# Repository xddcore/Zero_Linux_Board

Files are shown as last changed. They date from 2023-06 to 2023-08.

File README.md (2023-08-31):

<!--
 * @Author: Chengsen Dong 1034029664@qq.com
 * @Date: 2023-06-09 21:19:34
 * @LastEditors: Chengsen Dong 1034029664@qq.com
 * @LastEditTime: 2023-08-31 16:49:50
 * @FilePath: /Zero_Linux_Board/README.md
 * @Description: 这是默认设置,请设置`customMade`, 打开koroFileHeader查看配置 进行设置: https://github.com/OBKoro1/koro1FileHeader/wiki/%E9%85%8D%E7%BD%AE
-->
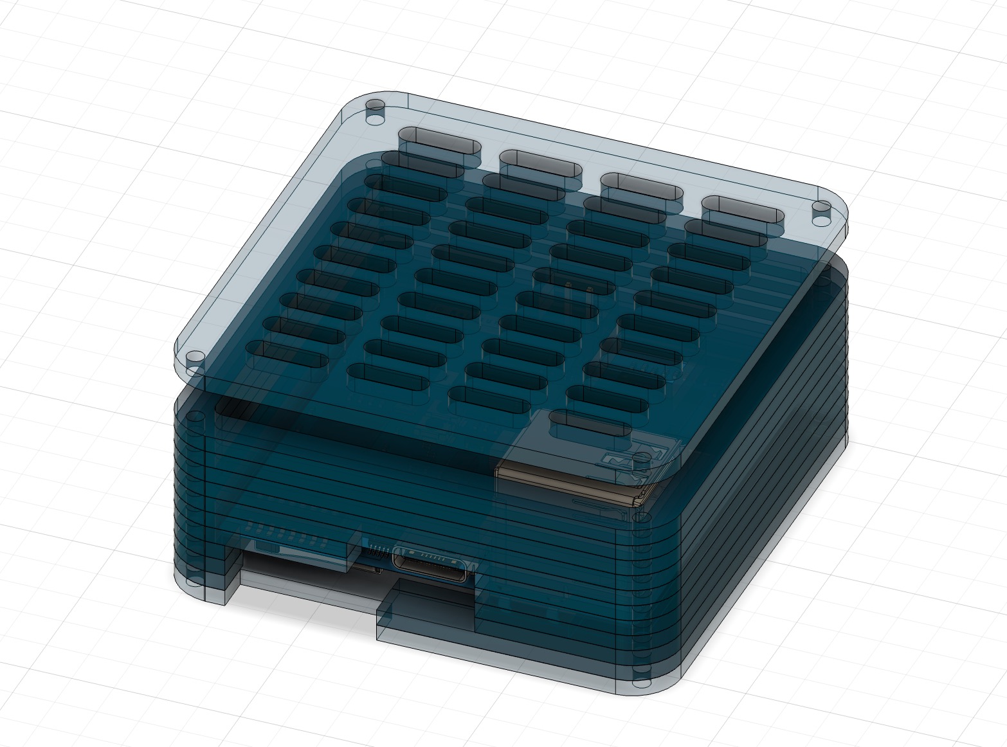
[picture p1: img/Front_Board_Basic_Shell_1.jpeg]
基础版正面1

# Zero Linux Board - 一个Linux小电脑。

>如果你喜欢此项目，欢迎为本项目点一个Star🌟

**核心板视频介绍**：[【自制】圆梦Linux小电脑](https://www.bilibili.com/video/BV1nN411S7BC)

**开源仓库介绍**：[【自制|开源】小白也可以轻松复现的Linux小电脑](https://www.bilibili.com/video/BV17u411V7ws/)

**透明探索版便携式小电脑**:[【自制】技术宅up耗时两个月，自制掌上触屏小电脑【硬核】【透明探索版】](https://www.bilibili.com/video/BV16h4y1Q7jv/)

## 介绍
本项目是xddcore同学在2023年6月2日启动的一个Linux开发板项目。本项目旨在纪念学生时代的结束(从初二至今9年的电子编程折腾生涯)。同时，设计一块板子来满足一些需要Linux生态但是又不需要很强性能的场景。

## 特性
1. **紧凑的设计**。PCB尺寸`49mm*49mm*1.6mm`，带壳尺寸`59mm*59mm*27mm`。
2. **差不多性能**。内置全志F1C200S(`ARM9@400Mhz+`)和RP2040(`双Cortex M0+处理器核心，最高133MHz`)。
3. **方便的开发方式**。仅一个Type-C接口可完成对F1C200S和RP2040的开发。另外还可通过F1C200S直接对RP2040进行编程。
4. **充分的外设**。`USB Hub(USB2.0*2)`，`2.4 GHz WIFI`，`3W扬声器`，`锂电池充放电管理`，`MPU6050`等。
5. **扩展板支持**。RP2040GPIO全引出(除2个ADC引脚外)，F1C200S部分核心外设引出。在后期将支持`ISP屏幕/墨水屏➕摄像头➕麦克风一体化扩展板`。
6. **透明探索版**。外壳主体采用12块2mm透明亚克力拼装而成。

- [Zero Linux Board - 一个Linux小电脑。](#)
  * [介绍](#介绍)
  * [特性](#特性)
  * [关于量产拼单活动](#关于量产拼单活动)
  * [目录结构](#0-目录结构)
  * [复现指南](#1-复现指南)
    + [1.1 硬件](#11-硬件)
      - [1.1.1 核心板PCB](#111-核心板pcb)
      - [1.1.2 扩展板PCB](#112-扩展板pcb)
      - [1.1.3 外壳](#113-外壳)
      - [1.1.4 其他硬件](#114-其他硬件)
      - [1.1.5 Type-C连接方式](#115-type-c连接方式)
      - [1.1.6 Type-C拨码开关配置](#116-type-c拨码开关配置)
    + [1.2 软件](#12-软件)
      - [1.2.1 驱动支持情况:](#121-驱动支持情况)
      - [1.2.2 快速验证](#122-快速验证)
      - [1.2.3 U-Boot](#123-u-boot)
      - [1.2.4 Linux主线(5.10.186)](#124-linux主线510186)
      - [1.2.5 使用Buildroot创建一个简易的rootfs来调试内核](#125-使用buildroot创建一个简易的rootfs来调试内核)
      - [1.2.6 使用debian来作为rootfs(apt install很舒服)](#126-使用debian来作为rootfsapt-install很舒服)
      - [1.2.7 debian-番外篇](#127-debian-番外篇)
    + [1.3 驱动开发](#13-驱动开发)
      - [1.3.1 Linux音频](#131-linux音频)
      - [1.3.2 ESP8266EX WIFI驱动](#132-esp8266ex-wifi驱动)
      - [1.3.3 MPU6050驱动](#133-mpu6050驱动)
      - [1.3.4 2.8寸ISP电容触摸屏驱动➕LVGL](#134-28寸isp电容触摸屏驱动lvgl)
      - [1.3.5 树莓派RP2040 USB驱动](#135-树莓派rp2040-usb驱动)
      - [1.3.6 语音识别与交互驱动](#136-语音识别与交互驱动)
    + [1.4 玩法推荐](#14-玩法)
      - [1.4.1 显示系统信息](#141-在isp屏幕上显示系统信息)
      - [1.4.2 显示图片](#142-在isp屏幕上显示图片)
      - [1.4.3 视频播放](#143-在isp屏幕上视频播放)
      - [1.4.4 usb摄像头](#144-usb摄像头)
      - [1.4.5 本地音乐播放](#145-本地音乐播放)
      - [1.4.6 网易云音乐播放音乐播放](#146-网易云音乐播放音乐播放)
      - [1.4.7 6轴陀螺仪](#147-6轴陀螺仪)
      - [1.4.8 lvgl](#148-lvgl)
      - [1.4.9 rp2040编程](#149-rp2040编程)
      - [1.4.10 智能助手chatgpt-35](#1410-智能助手chatgpt-35)
      - [1.4.11 登陆月球模拟器](#1411-登陆月球模拟器)
      - [1.4.12 nes模拟器](#1412-nes模拟器)
      - [1.4.13 opennna2.0神经网络框架](#1413-opennna20神经网络框架)
      - [1.4.14 搭建个人博客(typecho)](#1414-搭建个人博客typecho)
      - [1.4.15 内网穿透(rathole)](#1415-内网穿透rathole)
  * [1.5 一些图片](#15-一些图片)

---
## 关于量产拼单活动
xddcore zero Linux开发板软硬件全开源，大家可以选择自行复现。为了响应大家的购买需求，特地开启量产拼单活动。**本次量产拼单旨在集合大家的生产需求来拼单生产。这将显著显著降低大家制作开发板的成本，节约制作时间，并避免自行焊接带来问题。**      

**活动记录**      
230806：已成功拼单45块`Zero Linux Board`核心板，并全部成功交付。     
230817: 第二批量产拼单活动筹备进行中。本次将会拼单掌上小电脑套件(含核心板)。        

**活动参与方式**     

添加QQ群481227232，并填写支付问卷。

---

## 0. 目录结构

1. Hardware: 所有硬件相关资料

## 1. 复现指南

### 1.1 硬件

#### 1.1.1 核心板PCB
1. PCB尺寸:`49mm*49mm`，板厚`1.6mm`。
2. PCB层数:`4层`。
3. 电源线宽度`10mil`，信号线宽度`6mil`。
4. **WIFI天线50Ω阻抗匹配**: 下单时选用嘉立创`JLC0461H-7628`层压结构，经过计算，天线走线宽度为`13.75mil`。
5. 最小孔径/外径选择: 下单时选用嘉立创`0.25mm(外径0.35/0.4)`。
6. 大量封装采用`0402`，手焊推荐开钢网(节省成本可开小钢片)。

**硬件迭代**
|  版本号 |说明  |
|  ----  |---- |
| V1.0  | 完成初步设计 |
| V1.1  | 优化布线，引出IO。**Bug预警:已知原有TP5400升压电路10uH 0402电感功率较小，升压时会导致电感烧毁，请替换为额定电流大于1.5A的功率电感(TP5400最高输出1.5A(Vbat=3.8v))。** |
| V1.1-量产版本  | 优化布线，修复Bug。已稳定生产。 |

#### 1.1.2 扩展板PCB

|  名称 | 进度  | 说明  |
|  ----  | ---- | ---- |
| MINIPC 扩展板  | 已成功发布| 2.8寸ISP电容触摸屏,摄像头，麦克风，自定义按钮，全彩LED |
| 桌面机器人扩展板  | 已绘制完成，等待测试 | [稚晖君ElectronBot桌面机器人的Linux版本](https://github.com/xddcore/ElectronBot-Linux)|

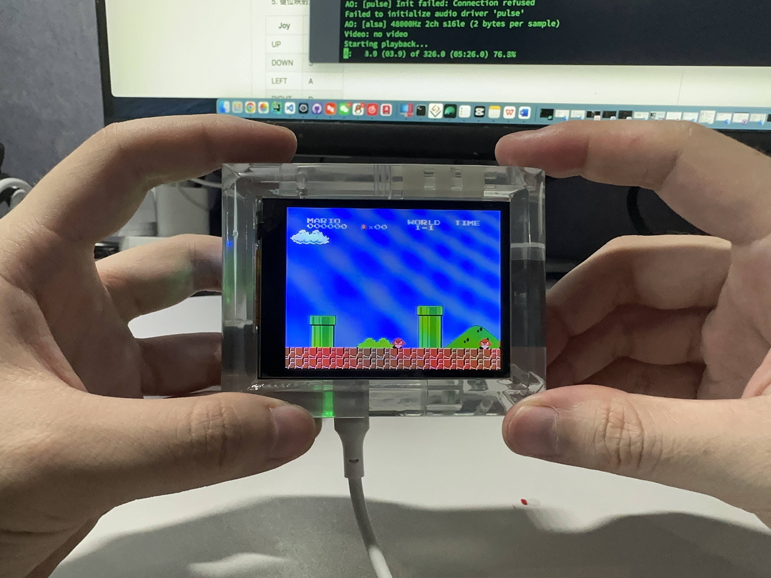
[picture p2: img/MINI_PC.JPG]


#### 1.1.3 外壳

##### 亚克力外壳
平衡美观和实用，预计推出两种亚克力外壳形式（得益于n\*2mm亚克力外壳方案带来Z轴方向的积木特性）：    
1. **透明探索款**：收藏陈列。全封闭外壳，避免进灰，搭配上蓝色阻焊层&1u沉金&JLC高清丝印，主打一个精致和帅。    
2. **基础款**：一般开发应用。Type-C&TF Card接口，内部含电池槽&扬声器槽，主控散热片支持&顶板散热孔。    

> Note:如果把亚克力外壳的图纸(.dwg文件)发到淘宝进行生产，某些厂家图纸尺寸单位可能识别成mm，导致外壳大小仅有5.9mm\*5.9mm。这时候需要提醒厂家外壳图纸单位为cm，外壳实际尺寸为5.9cm\*5.9cm。

关于亚克力外壳组装的说明(**非常重要**):    
在首次亚克力外壳设计中，采用了12块2mm厚度的亚克力。经过实际组装测试，亚克力高度缺少`2.8mm`,为了成功的组装采用如下方法修补:    

>方法一: 使用4颗2.8mm高度的M2防滑螺母垫高处理(M2防滑螺母安装在由下往上数的**第4块**亚克力上方)。效果图如下:    
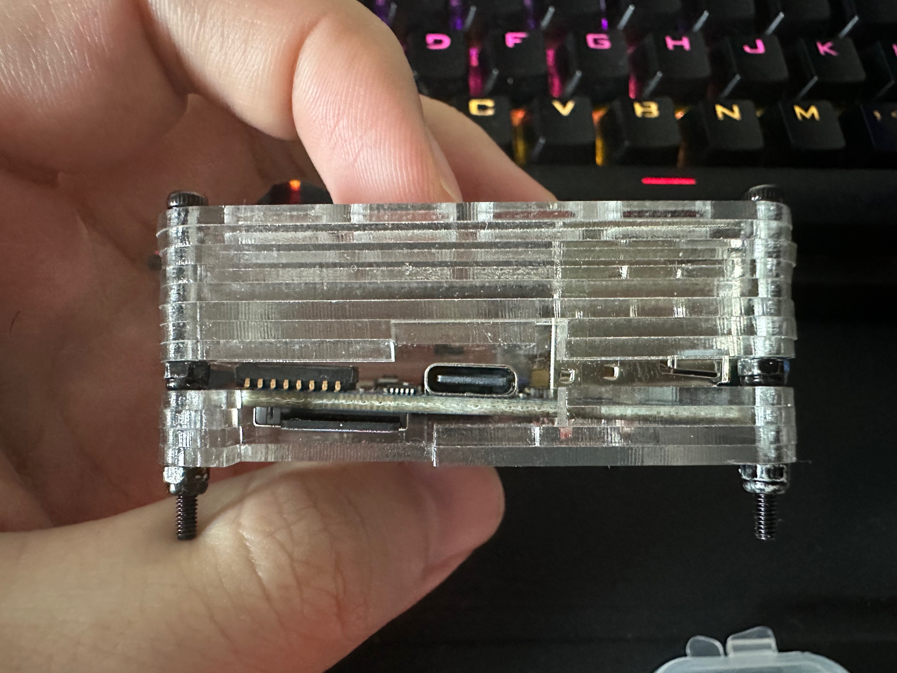
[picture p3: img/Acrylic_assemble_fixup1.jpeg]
Acrylic


>方法二: 在生产亚克力时，多生产一块3mm厚度的亚克力。最后共计生产**12块2mm厚度亚克力和1块3mm厚度亚克力**。    
**12块2mm厚度亚克力dwg生产文件**:[点我下载生产文件](https://github.com/xddcore/Zero_Linux_Board/blob/main/1.Hardware/1.1Zero_Linux_Board/SHELL_BASIC/Shell-basic_2D.dwg)     
**1块3mm厚度亚克力dwg生产文件**:[点我下载生产文件](https://github.com/xddcore/Zero_Linux_Board/blob/main/1.Hardware/1.1Zero_Linux_Board/SHELL_BASIC/Shell-basic_2D_3mm.dwg)

##### 3D打印外壳

1. MINI PC外壳:尺寸`90mm` \* `70mm` \* `34mm`。内置2.8寸ISP电容触摸屏，麦克风，iphone扬声器等，可玩性极高。

**MINI PC外壳螺丝要求:**
1. 2 \* M3螺丝长度**小于**`16.1mm`，**大于**`12.1mm`。**经实际测试，推荐`16mm`**
2. 2 \* M3螺丝长度**小于**`29.1mm`，**大于**`25.1mm`。**经实际测试，推荐`29mm`**
3. 2 \* M2螺丝长度**小于**`4mm`，**大于**`2mm`。**经实际测试，推荐`4mm`**

#### 1.1.4 其他硬件
1. 4 \*（M2螺丝+M2防滑螺母）。螺丝长度**需大于**`27mm`，M2防滑螺母厚度2.8mm。
2. 锂电池尺寸**需小于**`50mm*50mm*8mm`，锂电池接口为`XH2.54`。锂电池接口极性如下图:
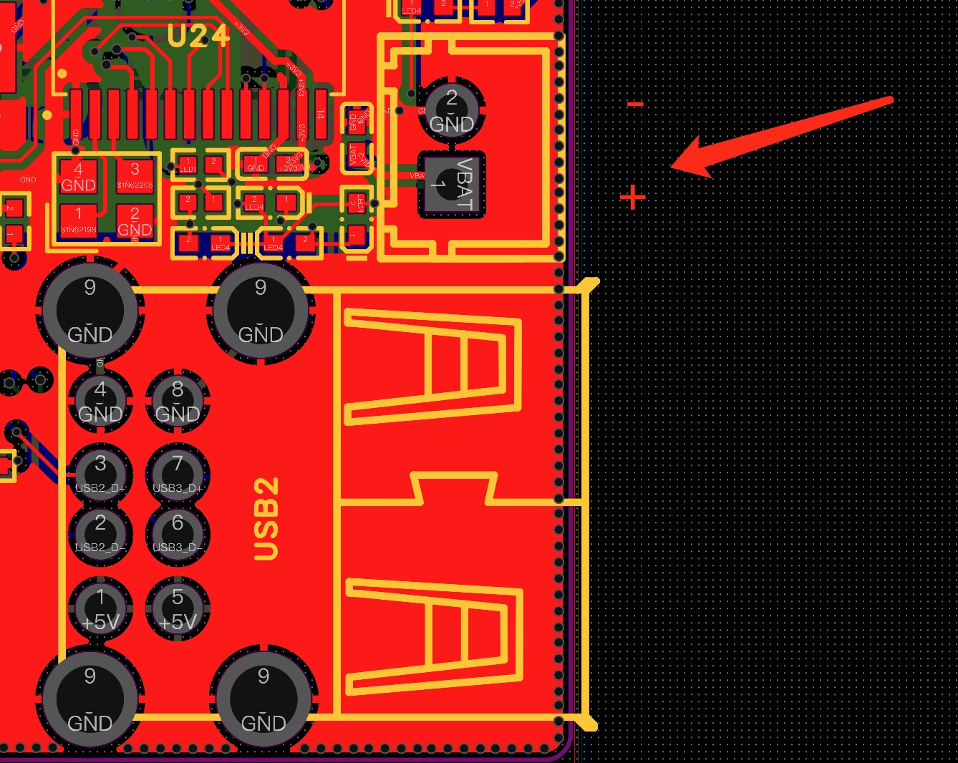
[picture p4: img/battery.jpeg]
battery
>
3. `F1C200S`和`ESP8266EX`散热片尺寸**需小于**`10mm*10mm*12mm`。

#### 1.1.5 Type-C连接方式
|  连接方式 | 功能  |
|  ----  | ---- |
| 正插  | 连接USB(具体取决于拨码开关配置) |
| 反插  | 连接F1C200S的串口0(USB-TTL)，用于输出串口终端 |

#### 1.1.6 Type-C拨码开关配置

|  功能(1-4Bit) | 1 Bit  | 2 Bit |  3 Bit |  4 Bit |
|  ----  | ---- | ---- | ---- | ---- |
| **F1C200S**的USB与`USB HUB`和`Type—C`断开连接  | OFF | OFF | OFF | OFF |
| **F1C200S**的USB与`USB HUB`的上行端口连接  | OFF | ON | OFF | ON |
| **F1C200S**的USB与`Type—C`连接  | ON | OFF | ON | OFF |

|  功能(5-8Bit) | 5 Bit  | 6 Bit |  7 Bit |  8 Bit |
|  ----  | ---- | ---- | ---- | ---- |
| **RP2040**的USB与`USB HUB`和`Type—C`断开连接  | OFF | OFF | OFF | OFF |
| **RP2040**的USB与`USB HUB`的下行端口连接  | OFF | ON | OFF | ON |
| **RP2040**的USB与`Type—C`连接  | ON | OFF | ON | OFF |

**如何跃过USB HUB进行通信**
操作:    
将F1C200s和RP2040的拨码开关都跳到连接Type-c，然后Type-c反面供电(连接F1C200s的串口)。此时F1c200s和RP2040直接连接。

### 1.2 软件

在软件章节开始前，想说明本项目的RAM&Flash资源情况如下:
| | F1C200S  | RP2040  |
|  ----  | ---- | ---- |
| RAM  | 64MB | 264KB |
| Flash  | 取决于SD卡容量(典型值32GB) | 16MB(SPI Flash) |

#### 1.2.1 驱动支持情况:
| 驱动名称  | 支持情况  | 
|  ----  | ---- |
| 状态指示LED  |  ✅ |
| WIFI网卡(ESP8266EX)  | ✅(WIFI速度下载806KB/s,上传729KB/s。以上结果由`speedtest`得出，仅供参考)  |
| SD卡(SDIO)  | ✅ |
| 视频硬解码  | ❌(开发中) |
| 音频codec  | ✅ |
| MPU6050(IIO Device)  | ✅ |
| 2.8寸ISP电容触摸屏  | ✅  |
| USB OTG/Host/Device | ✅ |
| USB HUB(键盘，U盘,摄像头)  | ✅ |
| F1C200S与RP2040的UART CDC通信；控制RP2040进入DFU模式，并对RP2040编程  | ✅ |

#### 1.2.2 快速验证

为了方便大家快速验证本开源项目，我提供以下SD卡镜像文件，大家可以以类似树莓派的玩法来游玩本开源项目。
| 镜像名称  | 下载链接  | 
|  ----  | ---- |
| xddcore_zero_debian_v5.10.186_230715.img.gz  |  [点我查看](https://github.com/xddcore/Zero_Linux_Board/releases/tag/Debian_v5.10.186_230715) |
| xddcore_zero_debian_v5.10.186_230810_Tiny.img(**最新**)  |  [点我查看](https://github.com/xddcore/Zero_Linux_Board/releases/tag/Debian_v5.10.186_230810) |

开发板工具包路径(相关软件会放置在里面)：
> /xddcore_toolbox

#### 1.2.3 U-Boot

1. 获取U-Boot源码
```
git clone https://github.com/xddcore/u-boot.git -b zero-v2023.07-rc4
```

2. 安装交叉编译工具链
```
sudo apt install gcc-arm-linux-gnueabi
```

3. 拉取配置文件
```
make xddcore_zero_defconfig
```
>[点我查看性能测试结果](#)     

**超频配置(CPU 408Mhz->720Mhz,DDR 156Mhz)** [点我查看超频配置](https://github.com/xddcore/Zero_Linux_Board/releases/tag/U-Boot_OverClock) 
```
make xddcore_zero_overclock_defconfig
```
4. 编译U-Boot
```
make ARCH=arm CROSS_COMPILE=arm-linux-gnueabi- -j4
```

5. 写入U-Boot至SD卡(假如为/dev/sdb)
> Note: SD卡在写入前请格式化为NTFS，数据无价，格式化前请做好数据备份。
```
sudo dd if=u-boot-sunxi-with-spl.bin of=/dev/sdb bs=1024 seek=8
```

6. 验证烧写结果,通过`gparted`软件查看。
```
sudo apt install gparted
```
7. 将SD卡插入Zero核心板背面的SD卡自弹插座中

8. 连接Type-C线缆(注意反面插入为USB-TTL功能)

9. 使用终端软件连接串口(波特率115200)
>xddcore同学在此使用的是Termius，大家可以选择自己喜欢的终端软件

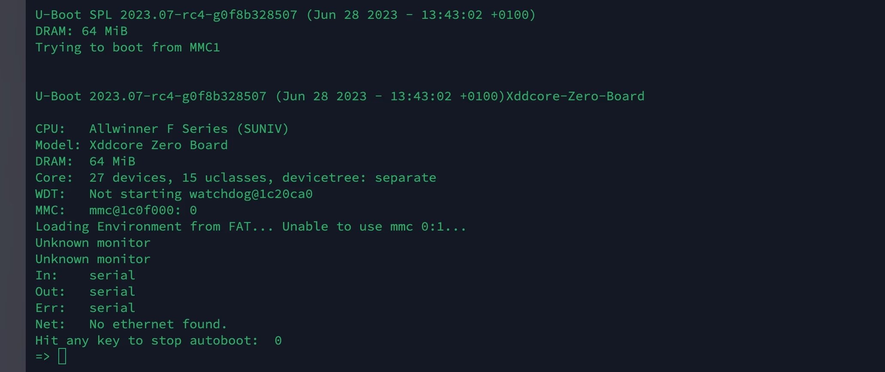
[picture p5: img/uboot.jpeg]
U-Boot


在此，我们可以看到U-boot成功在我们的板子上跑起来了。

#### 1.2.4 Linux主线(5.10.186)
1. 获取Linux内核源码
>长期支持版本: 6.1.36(因为内核逐渐向设备树方向发展，API换了不少(也删了不少)，啥驱动都得自己折腾)
```
git clone https://github.com/xddcore/linux.git -b zero-v6.1.36
```
>长期支持版本: 5.10.186(驱动丰富)
```
git clone https://github.com/xddcore/linux.git -b zero-v5.10.186-codec
```
在此我们使用`v5.10.186内核`进行接下来的开发。

2. 拉取内核配置
```
make ARCH=arm xddcore_zero_defconfig 
```

3. 编译内核
```
make ARCH=arm CROSS_COMPILE=arm-linux-gnueabi- -j4
```

4.将arch/arm/boot/zImage和dtb移入SD卡的FAT16分区

#### 1.2.5 使用Buildroot创建一个简易的rootfs来调试内核

1. 拉取Buildroot源码
```
git clone https://github.com/xddcore/buildroot.git -b zero-v2023.05
```

2. 拉取配置
```
make xddcore_zero_defconfig 
```

3. 使busybox支持`depmod``

```
sudo make busybox-menuconfig
Linux Module Utilities-> 选中depmod模块
```

4. `ssh`支持
```
sudo make menuconfig
Networking applications->Openssh，dhcpcd选中

Networking applications->
wireguard tools, 
wireless-regdb,
wireless tools(install shared library), 
wpa_supplicant,
wpan-tools,
xinetd,
xl2tp选中
```
5. 编译
```
sudo make busybox

sudo make -j4
```

6. 将rootfs放入EXT4分区

7. 将sd卡插入Zero

8. 串口终端波特率115200，用户名root，密码123456.至此根文件系统收工。

**如果启动的时候，console有如下报错:**

>can't open /dev/console: Permission denied 权限不足，是因为移动rootfs的时候rootfs被虚拟机用户所属，

**解决方案**:把所有文件所有者切回root

```
chown root * -R
```

#### 1.2.6 使用debian来作为rootfs(apt install很舒服)
1. 安装工具
```
sudo apt install qemu-user-static -y
sudo apt install debootstrap -y
```

2. 构建rootfs
```
sudo debootstrap --foreign --verbose --arch=armel  buster rootfs 

#如果梯子不太好用，也可以试试华为云的镜像
sudo debootstrap --foreign --verbose --arch=armel  buster rootfs http://mirrors.huaweicloud.com/debian/
```

3. 挂载
>此步坑点 apple m1 pro的pd虚拟机不支持arm 32bit(qemu)，换x86/x64即可解决。
```
cd rootfs
sudo mount --bind /dev dev/
sudo mount --bind /sys sys/
sudo mount --bind /proc proc/
sudo mount --bind /dev/pts dev/pts/
cd ..
sudo cp /usr/bin/qemu-arm-static rootfs/usr/bin/
sudo chmod +x rootfs/usr/bin/qemu-arm-static
sudo LC_ALL=C LANGUAGE=C LANG=C chroot rootfs /debootstrap/debootstrap --second-stage --verbose
sudo LC_ALL=C LANGUAGE=C LANG=C chroot rootfs
```

4. 预先安装一些软件(实现Zero板子的自力更生)
```
#网络
apt-get install wpasupplicant #安装WIFI配置相关的组件
apt-get install net-tools     #安装网络基础组件、如使用ifconfig等
apt-get install udhcpc        #当wifi连接成功后，需要用这个组件去获取IP地址

## 其他组件
apt-get install wireless-tools 
apt install sudo vim openssh-server htop
apt install pciutils usbutils acpi
```

5. 配置账号
```
passwd root
123456
```

6. 修改主机名
```
HOSTNAME=xddcore_zero(替换为你自己的主机名)
echo $HOSTNAME > /etc/hostname
sed -i '/localhost/s/$/\t'"$HOSTNAME"'/g' /etc/hosts
```

7. 允许root用户通过ssh登陆(只有一个root用户，所以这步非常重要，不然root无法通过ssh登陆)
```
vim /etc/ssh/sshd_config

在里面添加

PermitRootLogin yes
```

8. 退出rootfs，打包rootfs
```
exit  #退出chroot
rm rootfs/usr/bin/qemu-arm-static

cd rootfs
sudo umount   dev/pts/
sudo umount   dev/
sudo umount   sys/
sudo umount   proc/
sudo umount   dev/pts/

#打包文件(此时pwd在rootfs里面)
tar cvf ../rootfs.tar .    
```

9. 将rootfs解压到sd卡的ext4(rootfs)中

10. **启动后，通过串口命令行手动配网**

11. 安装WiFi驱动
```
insmod esp8089-spi.ko
```

12. 启动wlan0无线网卡
```
ifconfig wlan0 up
```

13. 新建wpa_supplicant配置文件(只需要进行一次)
```
vim /etc/wpa_supplicant/wpa_supplicant.conf

假如我有一个ssid为GL-MT1300-52d的无密码Wi-Fi。
填入以下内容:
ctrl_interface=DIR=/var/run/wpa_supplicant GROUP=netdev
update_config=1
country=CN

network={
  ssid="GL-MT1300-52d"
  key_mgmt=NONE
}

有密码的WIFI
ctrl_interface=DIR=/var/run/wpa_supplicant GROUP=netdev
update_config=1
country=CN

network={
    ssid="MyWifiNetwork"
    psk="MyPassword"
    key_mgmt=WPA-PSK #WPA2-PSK
    pairwise=CCMP
    group=CCMP
}

```

14. 连接WIFI
```
wpa_supplicant -B -i wlan0 -c /etc/wpa_supplicant/wpa_supplicant.conf 
```

15. 使用dhcp获取ip地址
```
udhcpc -i wlan0
```

16. 此时，板子成功上网了，使用ssh连接，Enjoy it!

17. 如果修改配置文件后，需要重启服务
```
pkill wpa_supplicant

sudo systemctl restart wpa_supplicant
```

#### 1.2.7 debian-番外篇
1. SWAP分区
64MB内存对于一台Linux小电脑来说，非常小。为了防止内存溢出，此处在sd卡中建立swap分区。
**使用以下命令创建512MB Swap分区**
```
dd if=/dev/zero of=/swap1 bs=1M count=512

mkswap /swap1

swapon /swap1

#永久性Swap分区
vim /etc/fstab
在内添加:
/swap1 swap swap defaults 0 0
```

2. 开机自动配网
>每次都串口cmd手动一个个输入命令，累死个人
>注意:此步骤需要串口cmd先手动登陆root用户，成功登陆之后，会自动运行配网脚本。

0.创建`/xddcore_toolbox/`文件夹，将`esp8089-spi.ko`放入。

1.编辑`~/.bashrc`文件
```
vim ~/.bashrc
```
2.在`~/.bashrc`文件末尾写入如下内容。
```
insmod /xddcore_toolbox/esp8089-spi.ko
ifconfig wlan0 up
wpa_supplicant -B -i wlan0 -c /etc/wpa_supplicant/wpa_supplicant.conf
udhcpc -i wlan0
```

**这里大家肯定有一个疑问，有没有不用登陆root用户，也可以自动配网的方式呢？答案是肯定的，操作步骤如下:**

1.创建/etc/init.d/net.sh脚本
```
vim /etc/init.d/net.sh
```
2.文件中填入如下内容
```
#!/bin/bash
 
### BEGIN INIT INFO
# Provides:          skeleton
# Required-Start:    $remote_fs $syslog
# Required-Stop:     $remote_fs $syslog
# Should-Start:      $portmap
# Should-Stop:       $portmap
# Default-Start:     2 3 4 5
# Default-Stop:      0 1 6
# Short-Description: Example initscript
### END INIT INFO
 
insmod /xddcore_toolbox/esp8089-spi.ko
ifconfig wlan0 up
wpa_supplicant -B -i wlan0 -c /etc/wpa_supplicant/wpa_supplicant.conf
udhcpc -i wlan0
 
exit 0
```
2.给脚本设置可运行权限
```
chmod 777 net.sh
```

3.设置脚本自动启动
> Note: 数字越大越晚执行，99代表最后执行。符合我们的需求。
```
update-rc.d net.sh defaults 99
```

4.如果未来不需要的时候，去除自动运行
```
update-rc.d net.sh remove
```

#### 1.2.8 系统性能测试
1.安装sysbench
```
wget https://github.com/akopytov/sysbench/archive/refs/tags/1.0.20.tar.gz
tar -zxvf 1.0.20.tar.gz
```

2.编译安装
```
apt install libtool m4 automake pkg-config
cd sysbench-1.0.20/
./autogen.sh
# Add --with-pgsql to build with PostgreSQL support
./configure --without-mysql
make -j
make install
```

3.安装完成后，查看sysbench版本
```
sysbench --version
```

4.性能测试
```
sysbench cpu --cpu-max-prime=200 run
```

### 1.3 驱动开发

#### 1.3.1 Linux音频
1.在debian下，查看声卡
```
cat /proc/asound/cards
```

2. 安装alsa-utils
```
apt install alsa-utils
```

3. 设置默认声卡
```
vim /etc/asound.conf

添加如下内容:
defaults.ctl.card 1
defaults.pcm.card 1
defaults.timer.card 1
```

4. 安装音频/视频播放软件
```
apt install mplayer 
```

5. 启动运放(PE10拉高 NUM=138)
```
echo 138 > /sys/class/gpio/export
echo out > /sys/class/gpio/gpio138/direction
echo 1 > /sys/class/gpio/gpio138/value
echo 138 > /sys/class/gpio/unexport
```

6. 播放歌曲
```
mplayer /xddcore_toolbox/you.mp3 
```

7. 网易云音乐命令行版本
```
apt install mpg123
apt install python3-pip
pip3 install NetEase-MusicBox
#这一步需要比较长的时间，耐心等待
#运行
musicbox
```

#### 1.3.2 ESP8266EX WIFI驱动

以下驱动代码**在buildroot生成的rootfs中**调试开发。

**性能参数:**
>WIFI速度下载806KB/s,上传729KB/s。以上结果由`speedtest`得出，仅供参考
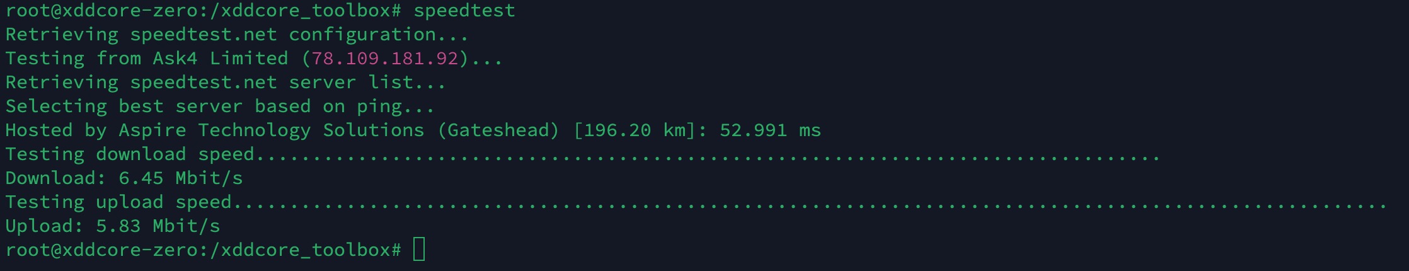
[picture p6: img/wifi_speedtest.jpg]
wifi_speedtest


>WIFI稳定性:
**路由器:**     
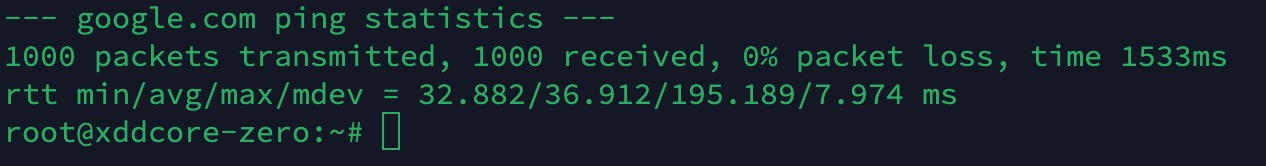
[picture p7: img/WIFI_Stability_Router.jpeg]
WIFI_Stability_Router

**手机热点:**
WIFI_Stability_SOFTAP 
用来测试的手机比较老了，等后面换一台再试试

1. 拉取代码
```
https://github.com/xddcore/ESP8089-SPI.git -b zero-esp8266ex
```

2. 编译代码
```
#KBUILD=换成自己下载的内核路径(我提供的内核:https://github.com/xddcore/linux/tree/zero-v5.10.186-codec)

make ARCH=arm CROSS_COMPILE=arm-linux-gnueabi- KBUILD=/home/parallels/xddcore/For_My_Board/linux
```

3. 此时在代码根目录下会生成`esp8089-spi.ko`文件，将驱动文件拷贝至sd卡的rootfs中。

4. SD卡插回开发板。

5. 在开发板的命令行下执行以下命令，加载驱动
```
insmod esp8089-spi.ko
```

此时应该会出现如下log:
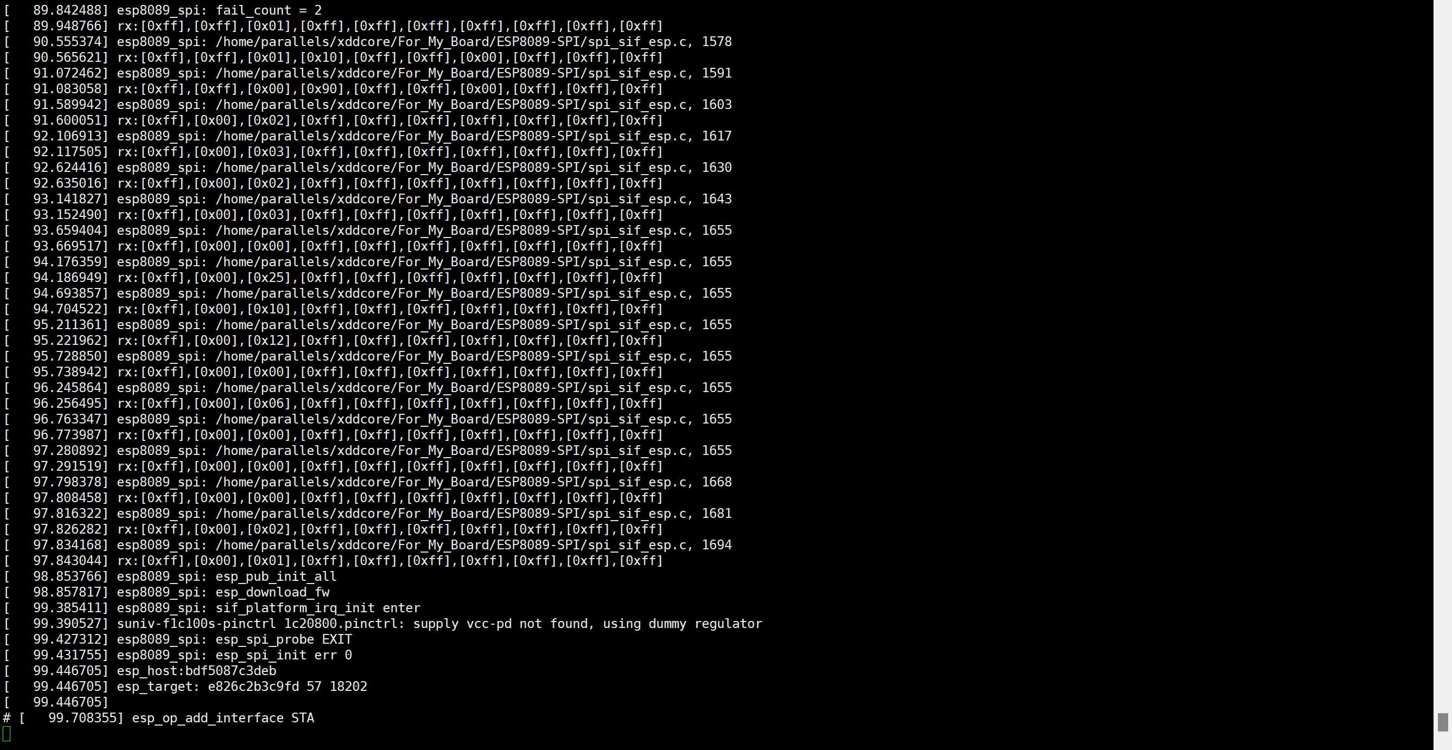
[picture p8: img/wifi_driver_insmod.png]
wifi_driver_insmod


wlan0会自动启动

6. 编辑 /etc/wpa_supplicant.conf 替换为自己的SSID和密码。
```
vi /etc/wpa_supplicant.conf
```
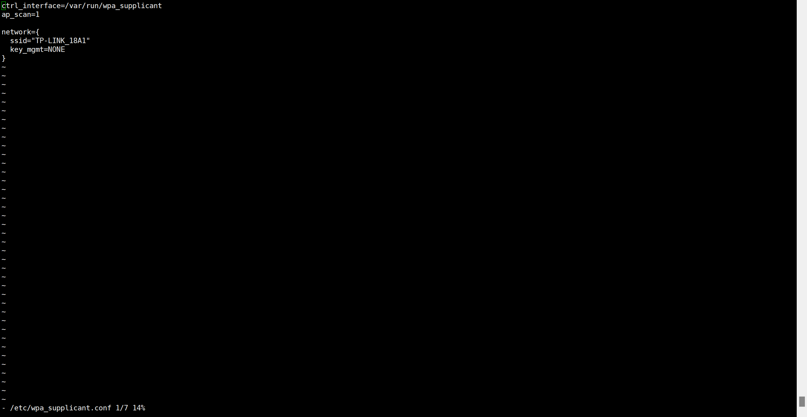
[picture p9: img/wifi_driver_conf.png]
wifi_driver_conf


7. 使用`wpa_supplicant`连接WIFI
```
wpa_supplicant -B -i wlan0 -c /etc/wpa_supplicant.conf 
```

8. 此时你可以运行一些简单的wpa_cli来检查工作状态
```
wpa_cli -i wlan0 scan #扫描附近的WIFI

wpa_cli -i wlan0 scan_results #展示扫描结果

wpa_cli -i wlan0 status #查看网卡状态
```

9. 运行结果如下:
```
root@xddcore-zero:~# wpa_cli -i wlan0 scan #扫描附近的WIFI
OK
root@xddcore-zero:~# 
root@xddcore-zero:~# wpa_cli -i wlan0 scan_results #展示扫描结果
bssid / frequency / signal level / flags / ssid
34:8f:27:5e:13:a8       2432    -80     [WPA2-EAP+FT/EAP-CCMP][ESS]     ASK4 Wireless (802.1x)
34:8f:27:9e:13:a8       2432    -81     [WPA2-PSK-CCMP][ESS]    Glasgow West End Staff
94:83:c4:0f:35:2f       2457    -56     [ESS]   GL-MT1300-52d
34:8f:27:1e:13:a8       2432    -81     [ESS]   ASK4 Wireless
root@xddcore-zero:~# 
root@xddcore-zero:~# wpa_cli -i wlan0 status #查看网卡状态
bssid=94:83:c4:0f:35:2f
freq=2457
ssid=GL-MT1300-52d
id=0
mode=station
pairwise_cipher=NONE
group_cipher=NONE
key_mgmt=NONE
wpa_state=COMPLETED
ip_address=192.168.8.193
p2p_device_address=18:fe:34:cd:30:ca
address=18:fe:34:cd:30:ca
uuid=8f4984fd-97c3-52a9-ac66-48aefaaa4498
```
10. 对于ssh之类的应用来说，你可能需要一个IP地址
```
udhcpc -i wlan0
```

最后获取IP如下图:
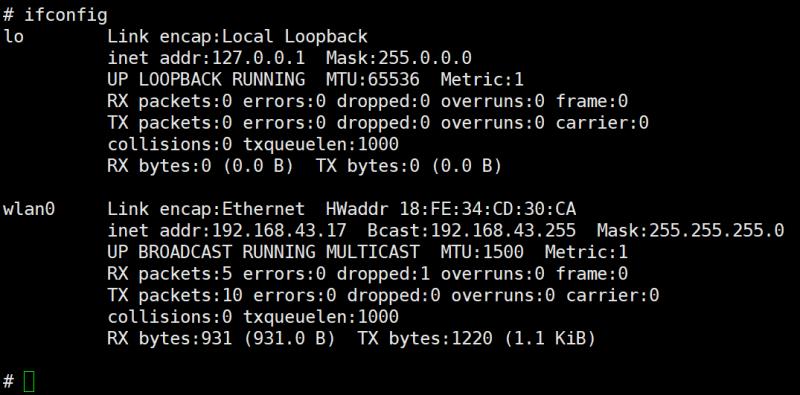
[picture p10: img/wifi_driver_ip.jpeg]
wifi_driver_ip


11. 至此，网卡驱动折腾完毕

#### 1.3.3 MPU6050驱动

1. 安装IIO设备工具包
```
apt install libiio-utils
```

2. 测试MPU6050
```
#读取所有IIO设备信息
iio-info
```

```
#读取MPU6050信息
iio_readdev -b 256 -s 1 iio:device0
#应该会返回乱码，因为以二进制返回
```

3. 查看当前采样率
```
cat /sys/bus/iio/devices/iio:device0/sampling_frequency
```

4. 查看可以设置的采样率
```
cat /sys/bus/iio/devices/iio:device0/sampling_frequency_available
```

5. 设置采样率
```
echo 500 > /sys/bus/iio/devices/iio:device0/sampling_frequency
```

6. 通过命令行读取加速度和角速度数据
```
while true; do
  x_accel=$(awk '{print $1*0.000598}' /sys/bus/iio/devices/iio:device0/in_accel_x_raw)
  y_accel=$(awk '{print $1*0.000598}' /sys/bus/iio/devices/iio:device0/in_accel_y_raw)
  z_accel=$(awk '{print $1*0.000598}' /sys/bus/iio/devices/iio:device0/in_accel_z_raw)
  x_anglvel=$(awk '{print $1*0.001064724}' /sys/bus/iio/devices/iio:device0/in_anglvel_x_raw)
  y_anglvel=$(awk '{print $1*0.001064724}' /sys/bus/iio/devices/iio:device0/in_anglvel_y_raw)
  z_anglvel=$(awk '{print $1*0.001064724}' /sys/bus/iio/devices/iio:device0/in_anglvel_z_raw)

  echo "X: $x_accel m/s², Y: $y_accel m/s², Z: $z_accel m/s²"
  echo "X: $x_anglvel °/s, Y: $y_anglvel °/s, Z: $z_anglvel °/s"
  echo " "
  sleep 1
done
```

7. 通过互补滤波计算X轴和Y轴角度
>Note: Bash的数学运算效率不是很高，所以响应速度比较慢。以下代码仅作为测试。

```
#!/bin/bash

# 初始角度
angle_x=0
angle_y=0

# 滤波因子，可以根据实际情况进行调整
alpha=0.98

while true; do
  x_accel=$(awk '{print $1*0.000598}' /sys/bus/iio/devices/iio:device0/in_accel_x_raw)
  y_accel=$(awk '{print $1*0.000598}' /sys/bus/iio/devices/iio:device0/in_accel_y_raw)
  z_accel=$(awk '{print $1*0.000598}' /sys/bus/iio/devices/iio:device0/in_accel_z_raw)
  x_anglvel=$(awk '{print $1*0.001064724}' /sys/bus/iio/devices/iio:device0/in_anglvel_x_raw)
  y_anglvel=$(awk '{print $1*0.001064724}' /sys/bus/iio/devices/iio:device0/in_anglvel_y_raw)
  z_anglvel=$(awk '{print $1*0.001064724}' /sys/bus/iio/devices/iio:device0/in_anglvel_z_raw)

  # 根据角速度计算角度增量，考虑到陀螺仪给出的是角速度，我们需要乘以时间间隔
  angle_x=$(echo "$angle_x + $x_anglvel * 0.01" | bc)
  angle_y=$(echo "$angle_y + $y_anglvel * 0.01" | bc)

  # 根据加速度计算角度，需要将加速度转换为角度
  accel_angle_x=$(echo "a( $y_accel / sqrt( $x_accel*$x_accel + $z_accel*$z_accel ) ) * 180 / 3.14159265" | bc -l)
  accel_angle_y=$(echo "a( $x_accel / sqrt( $y_accel*$y_accel + $z_accel*$z_accel ) ) * 180 / 3.14159265" | bc -l)

  # 使用互补滤波计算角度
  angle_x=$(echo "$alpha * $angle_x + (1 - $alpha) * $accel_angle_x" | bc)
  angle_y=$(echo "$alpha * $angle_y + (1 - $alpha) * $accel_angle_y" | bc)

  echo "X: $x_accel m/s², Y: $y_accel m/s², Z: $z_accel m/s²"
  echo "X: $x_anglvel °/s, Y: $y_anglvel °/s, Z: $z_anglvel °/s"
  echo "Angle X: $angle_x °, Angle Y: $angle_y °"
  echo " "
  sleep 0.01
done
```

8. 利用c语言实现一个高效的互补滤波(以下代码写入`mpu6050.c`文件)
```
#include <stdio.h>
#include <math.h>
#include <unistd.h>
#include <time.h>

#define ALPHA 0.98
#define DT 0.001  // 1ms
#define PRINT_INTERVAL 0.1  // 100ms
#define GYRO_SCALE_FACTOR 0.001064724
#define ACCEL_SCALE_FACTOR 0.000598

double get_value(char *filename) {
    double value;
    FILE *fp = fopen(filename, "r");
    fscanf(fp, "%lf", &value);
    fclose(fp);
    return value;
}

int main() {
    double angle_x = 0;
    double angle_y = 0;
    int print_counter = 0;
    int print_interval_counts = PRINT_INTERVAL / DT;

    struct timespec delay = {0, DT * 1e9}; // Delay for nanosleep

    while (1) {
        double x_accel = get_value("/sys/bus/iio/devices/iio:device0/in_accel_x_raw") * ACCEL_SCALE_FACTOR;
        double y_accel = get_value("/sys/bus/iio/devices/iio:device0/in_accel_y_raw") * ACCEL_SCALE_FACTOR;
        double z_accel = get_value("/sys/bus/iio/devices/iio:device0/in_accel_z_raw") * ACCEL_SCALE_FACTOR;
        double x_anglvel = get_value("/sys/bus/iio/devices/iio:device0/in_anglvel_x_raw") * GYRO_SCALE_FACTOR;
        double y_anglvel = get_value("/sys/bus/iio/devices/iio:device0/in_anglvel_y_raw") * GYRO_SCALE_FACTOR;
        double z_anglvel = get_value("/sys/bus/iio/devices/iio:device0/in_anglvel_z_raw") * GYRO_SCALE_FACTOR;

        angle_x += x_anglvel * DT;
        angle_y += y_anglvel * DT;

        double accel_angle_x = atan2(y_accel, sqrt(pow(x_accel, 2) + pow(z_accel, 2))) * 180 / M_PI;
        double accel_angle_y = atan2(x_accel, sqrt(pow(y_accel, 2) + pow(z_accel, 2))) * 180 / M_PI;

        angle_x = ALPHA * angle_x + (1 - ALPHA) * accel_angle_x;
        angle_y = ALPHA * angle_y + (1 - ALPHA) * accel_angle_y;

        if (++print_counter >= print_interval_counts) {
            printf("X: %lf m/s², Y: %lf m/s², Z: %lf m/s²\n", x_accel, y_accel, z_accel);
            printf("X: %lf °/s, Y: %lf °/s, Z: %lf °/s\n", x_anglvel, y_anglvel, z_anglvel);
            printf("Angle X: %lf °, Angle Y: %lf °\n\n", angle_x, angle_y);
            print_counter = 0;
        }

        nanosleep(&delay, NULL);
    }

    return 0;
}

```

9. 卡尔曼滤波(性能优于互补滤波)(以下代码写入`mpu6050.c`文件)
```
#include <stdio.h>
#include <math.h>
#include <unistd.h>
#include <time.h>

#define DT 0.001  // 1ms
#define PRINT_INTERVAL 0.1  // 100ms
#define GYRO_SCALE_FACTOR 0.001064724
#define ACCEL_SCALE_FACTOR 0.000598

double get_value(char *filename) {
    double value;
    FILE *fp = fopen(filename, "r");
    fscanf(fp, "%lf", &value);
    fclose(fp);
    return value;
}

// 卡尔曼滤波器的结构
typedef struct {
    double q;  // 过程噪声协方差
    double r;  // 测量噪声协方差
    double x;  // 最优化估算值
    double p;  // 估算误差协方差
    double k;  // 卡尔曼增益
} kalman_state;

// 卡尔曼滤波器的初始化
void kalman_init(kalman_state *state, double q, double r, double p, double initial_value) {
    state->q = q;
    state->r = r;
    state->p = p;
    state->x = initial_value;
}

// 卡尔曼滤波器的更新
void kalman_update(kalman_state *state, double measurement) {
    // 预测
    state->p += state->q;

    // 更新
    state->k = state->p / (state->p + state->r);
    state->x += state->k * (measurement - state->x);
    state->p = (1 - state->k) * state->p;
}

int main() {
    struct timespec delay = {0, DT * 1e9}; // Delay for nanosleep
    int print_counter = 0;
    int print_interval_counts = PRINT_INTERVAL / DT;

    kalman_state state_x;
    kalman_state state_y;
    kalman_init(&state_x, 0.125, 32, 1023, 0);  // You may need to adjust these values based on your sensor's characteristics
    kalman_init(&state_y, 0.125, 32, 1023, 0);  // You may need to adjust these values based on your sensor's characteristics

    while (1) {
        double x_accel = get_value("/sys/bus/iio/devices/iio:device0/in_accel_x_raw") * ACCEL_SCALE_FACTOR;
        double y_accel = get_value("/sys/bus/iio/devices/iio:device0/in_accel_y_raw") * ACCEL_SCALE_FACTOR;
        double z_accel = get_value("/sys/bus/iio/devices/iio:device0/in_accel_z_raw") * ACCEL_SCALE_FACTOR;
        double x_anglvel = get_value("/sys/bus/iio/devices/iio:device0/in_anglvel_x_raw") * GYRO_SCALE_FACTOR;
        double y_anglvel = get_value("/sys/bus/iio/devices/iio:device0/in_anglvel_y_raw") * GYRO_SCALE_FACTOR;
        double z_anglvel = get_value("/sys/bus/iio/devices/iio:device0/in_anglvel_z_raw") * GYRO_SCALE_FACTOR;

        double accel_angle_x = atan2(y_accel, sqrt(pow(x_accel, 2) + pow(z_accel, 2))) * 180 / M_PI;
        double accel_angle_y = atan2(x_accel, sqrt(pow(y_accel, 2) + pow(z_accel, 2))) * 180 / M_PI;

        kalman_update(&state_x, accel_angle_x);
        kalman_update(&state_y, accel_angle_y);

        if (++print_counter >= print_interval_counts) {
            printf("X: %lf m/s², Y: %lf m/s², Z: %lf m/s²\n", x_accel, y_accel, z_accel);
            printf("X: %lf °/s, Y: %lf °/s, Z: %lf °/s\n", x_anglvel, y_anglvel, z_anglvel);
            printf("Angle X: %lf °, Angle Y: %lf °\n\n", state_x.x, state_y.x);
            print_counter = 0;
            print_counter = 0;
        }

        nanosleep(&delay, NULL);
    }

    return 0;
}

```

10. 编译
```
gcc -o mpu6050 mpu6050.c -lm
```
11. 运行
```
./mpu6050
```

12. **耐心大作战|一个利用X轴角度和Y轴角度设计的小游戏**
>在这个游戏中，你将看到一个由"."组成的20x20的网格。玩家（标记为"P"）通过调整设备的角度来在屏幕上移动P。目标位置（标记为"T"）在网格的一个固定位置。当玩家到达目标位置时，游戏结束，并显示"Congratulations, you won!"的消息。

**新手模式**(以下代码写入`mpu6050_game.c`文件)

```
#include <stdio.h>
#include <stdlib.h>
#include <math.h>
#include <unistd.h>
#include <time.h>

#define DT 0.001  // 1ms
#define PRINT_INTERVAL 0.05  // 50ms
#define GYRO_SCALE_FACTOR 0.001064724
#define ACCEL_SCALE_FACTOR 0.000598
#define BOARD_SIZE 20

int TARGET_X=0,TARGET_Y=0;

double get_value(char *filename) {
    double value;
    FILE *fp = fopen(filename, "r");
    fscanf(fp, "%lf", &value);
    fclose(fp);
    return value;
}

typedef struct {
    double q;  
    double r;  
    double x;  
    double p;  
    double k;  
} kalman_state;

void kalman_init(kalman_state *state, double q, double r, double p, double initial_value) {
    state->q = q;
    state->r = r;
    state->p = p;
    state->x = initial_value;
}

void kalman_update(kalman_state *state, double measurement) {
    state->p += state->q;
    state->k = state->p / (state->p + state->r);
    state->x += state->k * (measurement - state->x);
    state->p = (1 - state->k) * state->p;
}

void print_board(int player_x, int player_y) {
    for(int i=0; i<BOARD_SIZE; i++) {
        for(int j=0; j<BOARD_SIZE; j++) {
            if(i == player_x && j == player_y) {
                printf("P ");
            } else if(i == TARGET_X && j == TARGET_Y) {
                printf("T ");
            } else {
                printf(". ");
            }
        }
        printf("\n");
    }
}

int main() {
    srand(time(NULL));
    TARGET_X = rand() % BOARD_SIZE;
    TARGET_Y = rand() % BOARD_SIZE;
    struct timespec delay = {0, DT * 1e9}; 
    int print_counter = 0;
    int print_interval_counts = PRINT_INTERVAL / DT;

    kalman_state state_x;
    kalman_state state_y;
    kalman_init(&state_x, 0.125, 32, 1023, 0);
    kalman_init(&state_y, 0.125, 32, 1023, 0); 

    int player_x = BOARD_SIZE / 2;
    int player_y = BOARD_SIZE / 2;

    while (1) {
        double x_accel = get_value("/sys/bus/iio/devices/iio:device0/in_accel_x_raw") * ACCEL_SCALE_FACTOR;
        double y_accel = get_value("/sys/bus/iio/devices/iio:device0/in_accel_y_raw") * ACCEL_SCALE_FACTOR;
        double z_accel = get_value("/sys/bus/iio/devices/iio:device0/in_accel_z_raw") * ACCEL_SCALE_FACTOR;

        double accel_angle_x = atan2(y_accel, sqrt(pow(x_accel, 2) + pow(z_accel, 2))) * 180 / M_PI;
        double accel_angle_y = atan2(x_accel, sqrt(pow(y_accel, 2) + pow(z_accel, 2))) * 180 / M_PI;

        kalman_update(&state_x, accel_angle_x);
        kalman_update(&state_y, accel_angle_y);

        // 根据角度调整角色的位置
        if(state_x.x > 15 && player_x > 0) {
            player_x--;
        } else if(state_x.x < -15 && player_x < BOARD_SIZE - 1) {
            player_x++;
        }

        if(state_y.x > 15 && player_y < BOARD_SIZE - 1) {
            player_y++;
        } else if(state_y.x < -15 && player_y > 0) {
            player_y--;
        }

        // 清屏并打印游戏版面
        system("clear");
        print_board(player_x, player_y);

        // 检查角色是否已经到达目标
        if(player_x == TARGET_X && player_y == TARGET_Y) {
            printf("Congratulations, you won!\n");
            break;
        }

        nanosleep(&delay, NULL);
    }

    return 0;
}
```

**高难度模式**(以下代码写入`mpu6050_game.c`文件)
```
#include <stdio.h>
#include <stdlib.h>
#include <math.h>
#include <unistd.h>
#include <time.h>

#define DT 0.001  // 1ms
#define PRINT_INTERVAL 0.05  // 50ms
#define GYRO_SCALE_FACTOR 0.001064724
#define ACCEL_SCALE_FACTOR 0.000598
#define BOARD_SIZE 20

int TARGET_X=0,TARGET_Y=0;

char last_board[BOARD_SIZE][BOARD_SIZE];

double get_value(char *filename) {
    double value;
    FILE *fp = fopen(filename, "r");
    fscanf(fp, "%lf", &value);
    fclose(fp);
    return value;
}

typedef struct {
    double q;  
    double r;  
    double x;  
    double p;  
    double k;  
} kalman_state;

void kalman_init(kalman_state *state, double q, double r, double p, double initial_value) {
    state->q = q;
    state->r = r;
    state->p = p;
    state->x = initial_value;
}

void kalman_update(kalman_state *state, double measurement) {
    state->p += state->q;
    state->k = state->p / (state->p + state->r);
    state->x += state->k * (measurement - state->x);
    state->p = (1 - state->k) * state->p;
}

void print_board(int player_x, int player_y) {
    for(int i=0; i<BOARD_SIZE; i++) {
        for(int j=0; j<BOARD_SIZE; j++) {
            char new_char;
            if(i == player_x && j == player_y) {
                new_char = 'P';
            } else if(i == TARGET_X && j == TARGET_Y) {
                new_char = 'T';
            } else {
                new_char = '.';
            }
            if(last_board[i][j] != new_char) {
                printf("\033[%d;%dH%c", i+1, j*2+1, new_char);
                fflush(stdout); // 确保字符被立即打印
                last_board[i][j] = new_char;
            }
        }
    }
}

int main() {
    srand(time(NULL));
    system("clear");
    TARGET_X = rand() % BOARD_SIZE;
    TARGET_Y = rand() % BOARD_SIZE;
    struct timespec delay = {0, DT * 1e9}; 
    int print_counter = 0;
    int print_interval_counts = PRINT_INTERVAL / DT;

    kalman_state state_x;
    kalman_state state_y;
    kalman_init(&state_x, 0.125, 32, 1023, 0);
    kalman_init(&state_y, 0.125, 32, 1023, 0); 

    int player_x = BOARD_SIZE / 2;
    int player_y = BOARD_SIZE / 2;

    while (1) {
        double x_accel = get_value("/sys/bus/iio/devices/iio:device0/in_accel_x_raw") * ACCEL_SCALE_FACTOR;
        double y_accel = get_value("/sys/bus/iio/devices/iio:device0/in_accel_y_raw") * ACCEL_SCALE_FACTOR;
        double z_accel = get_value("/sys/bus/iio/devices/iio:device0/in_accel_z_raw") * ACCEL_SCALE_FACTOR;

        double accel_angle_x = atan2(y_accel, sqrt(pow(x_accel, 2) + pow(z_accel, 2))) * 180 / M_PI;
        double accel_angle_y = atan2(x_accel, sqrt(pow(y_accel, 2) + pow(z_accel, 2))) * 180 / M_PI;

        kalman_update(&state_x, accel_angle_x);
        kalman_update(&state_y, accel_angle_y);

        // 根据角度调整角色的位置
        if(state_x.x > 15 && player_x > 0) {
            player_x--;
        } else if(state_x.x < -15 && player_x < BOARD_SIZE - 1) {
            player_x++;
        }

        if(state_y.x > 15 && player_y < BOARD_SIZE - 1) {
            player_y++;
        } else if(state_y.x < -15 && player_y > 0) {
            player_y--;
        }

        // 打印游戏版面
        print_board(player_x, player_y);

        // 检查角色是否已经到达目标
        if(player_x == TARGET_X && player_y == TARGET_Y) {
            printf("\033[%d;%dH", BOARD_SIZE + 1, 1); // 将光标移动到版面下方
            printf("Congratulations, you won!\n");
            break;
        }

        nanosleep(&delay, NULL);
    }

    return 0;
}

```

13. 编译
```
gcc -o mpu6050_game mpu6050_game.c -lm
```
14. 运行
```
./mpu6050_game
```

#### 1.3.4 2.8寸ISP电容触摸屏驱动&LVGL

0. 下载交叉编译工具链
```
#!/bin/sh

HOST=arm-linux-gnueabi
SCRIPT_PATH=$(pwd)

#修改源码包解压后的名称
MAJOR_NAME=gcc-arm-linux-gnueabi

#修改需要下载的源码版本前缀和后缀
OPENSRC_VER_PREFIX=7.2
OPENSRC_VER_SUFFIX=.1

PACKAGE_NAME=${MAJOR_NAME}-${OPENSRC_VER_PREFIX}${OPENSRC_VER_SUFFIX}

#定义压缩包名称
COMPRESS_PACKAGE=gcc-linaro-7.2.1-2017.11-x86_64_arm-linux-gnueabi.tar.xz

#定义编译后安装--生成的文件,文件夹位置路径
INSTALL_PATH=/opt/${PACKAGE_NAME}

#无需修改--下载地址
DOWNLOAD_LINK=https://releases.linaro.org/components/toolchain/binaries/7.2-2017.11/arm-linux-gnueabi/${COMPRESS_PACKAGE}

#下载源码包
do_download_src () {
   echo "start download ${COMPRESS_PACKAGE}..."
   if [ ! -f "${COMPRESS_PACKAGE}" ];then
      if [ ! -d "${PACKAGE_NAME}" ];then
        wget -c ${DOWNLOAD_LINK}
      fi
   fi
   echo "\033[1;33mdone...\033[0m"
}

#解压源码包
do_tar_package () {
   echo "start unpacking the ${PACKAGE_NAME} package ..."

   mkdir -p ${INSTALL_PATH}

   if [ ! -d "${PACKAGE_NAME}" ];then
      tar -xf ${COMPRESS_PACKAGE} -C ${INSTALL_PATH} --strip-components=1
   fi
   echo "done..."
}

#删除下载的文件
do_delete_file () {
   cd ${SCRIPT_PATH}
   if [ -f "${PACKAGE_NAME}" ];then
      sudo rm -f ${PACKAGE_NAME}
   fi
}

do_download_src
do_tar_package
# do_delete_file

exit $?
```

1. 拉取源码
**所有控件展示的demo**
```
git clone https://github.com/xddcore/lv_port_linux_frame_buffer -b zero-lvgl
```
**心率，血压demo**
```
git clone https://github.com/xddcore/lv_port_linux_frame_buffer -b zero_lvgl_heartrate
```
2. 拉取子模块
```
cd lv_port_linux_frame_buffer/
git submodule update --init --recursive
```

3. 生成Makefile，然后编译源码
```
#ls看一下，如有/build，则请先执行rm -rf build/
mkdir build
cd build
cmake ..
make
```

4. 运行
```
./lvgl_fb
```

一些优化体验的指令
```
echo -e "\033[?25l" > /dev/tty1 #关闭光标
echo -e "\033[?25h" > /dev/tty1 #开启光标
```

#### 1.3.5 树莓派RP2040 USB驱动

RP2040的`RUN(PE8，NUM=136)引脚`以及`BOOT(PE7，NUM=135)引脚`受到F1C200S的控制，因此F1C200S可以方便的对RP2040进行编程。

1. 操作RP2040进入DFU模式
```
echo 136 > /sys/class/gpio/export
echo 135 > /sys/class/gpio/export
echo out > /sys/class/gpio/gpio136/direction
echo out > /sys/class/gpio/gpio135/direction
echo 0 > /sys/class/gpio/gpio136/value
echo 0 > /sys/class/gpio/gpio135/value
sleep 1
echo 1 > /sys/class/gpio/gpio136/value
sleep 1
echo 1 > /sys/class/gpio/gpio135/value
echo 136 > /sys/class/gpio/unexport
echo 135 > /sys/class/gpio/unexport
```

2. 将F1C200s USB模式切换为Host
```
echo host > /sys/devices/platform/soc/1c13000.usb/musb-hdrc.1.auto/mode

#补充一下如果要换成device模式的话，执行以下代码:
echo peripheral > /sys/devices/platform/soc/1c13000.usb/musb-hdrc.1.auto/mode
```

3. RP2040已进入DFU模式(此时在Linux上表现为一个存储设备)
```
fdisk -l
```
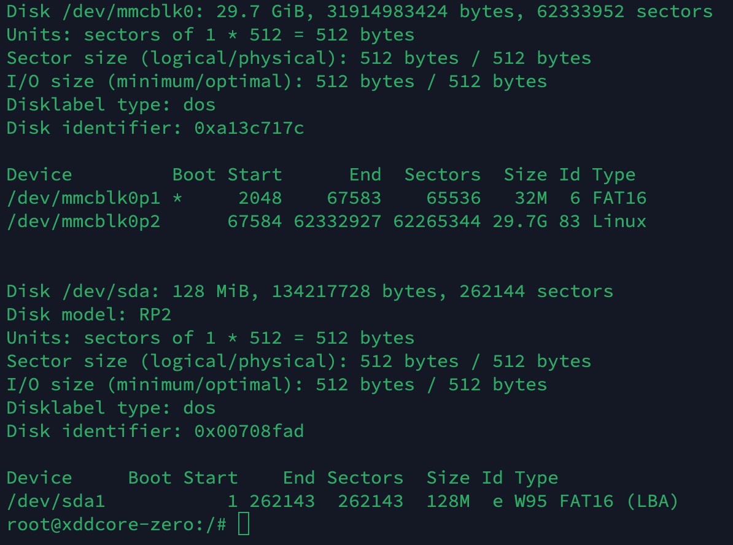
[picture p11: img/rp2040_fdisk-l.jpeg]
rp2040_fdisk-l


4. 挂载RP2040
```
#此处根据实际情况修改可能为sda1或sdb1
mount -t vfat /dev/sda1 /media
```

5. 下载MicroPython固件
```
wget https://micropython.org/download/rp2-pico/rp2-pico-latest.uf2
```

**Bug修复**    
**Bug现象**:重启后固件丢失，以及flash size无法正确返回的问题。     
**SPI Flash型号**:W25Q128JV      
**解决办法**:    
根据数据手册，`Clock frequency for Read Data instruction (03h) fR D.C. 50 MHz`，最大读取数据指令时钟为50Mhz。MicroPython配置的PICO_FLASH_SPI_CLKDIV=4时，时钟约为60Mhz，将会导致SPI Flash无法工作。我们在编译程序时，需要手动降低至40Mhz(添加编译选项 PICO_FLASH_SPI_CLKDIV= 6,BOOT2_S_CFLAGS ?= -DPICO_FLASH_SPI_CLKDIV= 6)。     
**参考:**
> https://github.com/adafruit/circuitpython/issues/4377        
> https://github.com/raspberrypi/pico-sdk/issues/1304 (两种fixup思路)    
> https://github.com/adafruit/circuitpython/commit/aec03a409f66cdb90e1b51c7ffb827750eadd830    

5. 下载CircuitPython固件
```
wget https://downloads.circuitpython.org/bin/raspberry_pi_pico/en_US/adafruit-circuitpython-raspberry_pi_pico-en_US-8.2.0.uf2
```

5. Pico-SDK
```
git clone https://github.com/raspberrypi/pico-sdk
```
> Note: Pico-SDK的SPI Flash时钟部分和MicroPython具有相同Bug，参考上述方法进行修复。

6. 烧录固件至RP2040
```
#micropython
cp /xddcore_toolbox/rp2-pico-latest.uf2 /media/

#circuitpython
cp /xddcore_toolbox/adafruit-circuitpython-raspberry_pi_pico-en_US-8.2.0.uf2 /media/
```

7. 成功烧录后，你将看到如下提示：
```
[  164.934750] usb 1-1: USB disconnect, device number 2
[  164.948943] blk_update_request: I/O error, dev sda, sector 260 op 0x1:(WRITE) flags 0x0 phys_seg 1 prio class 0
[  164.959264] Buffer I/O error on dev sda1, logical block 259, lost async page write
[  165.499616] usb 1-1: new full-speed USB device number 3 using musb-hdrc
[  165.692558] cdc_acm 1-1:1.0: ttyACM0: USB ACM device
```

8. 装个MINICOM(与MicroPython进行交互)
```
apt install minicom
```

9. 查看USB串口设备
>USB 串行设备通常显示为 /dev/ttyUSBx 或 /dev/ttyACMx，其中 x 是一个数字。
```
 ls /dev/tty*
```

10. 连接RP2040
```
minicom -o -D /dev/ttyACM0
```
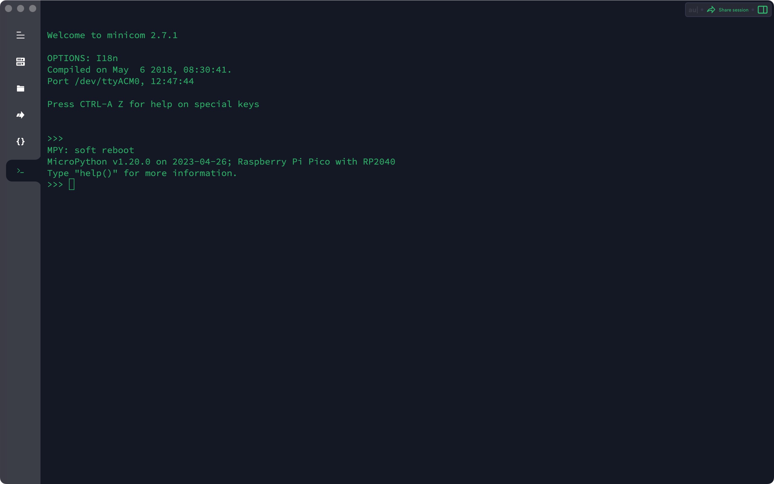
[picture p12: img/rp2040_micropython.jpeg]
rp2040_micropython

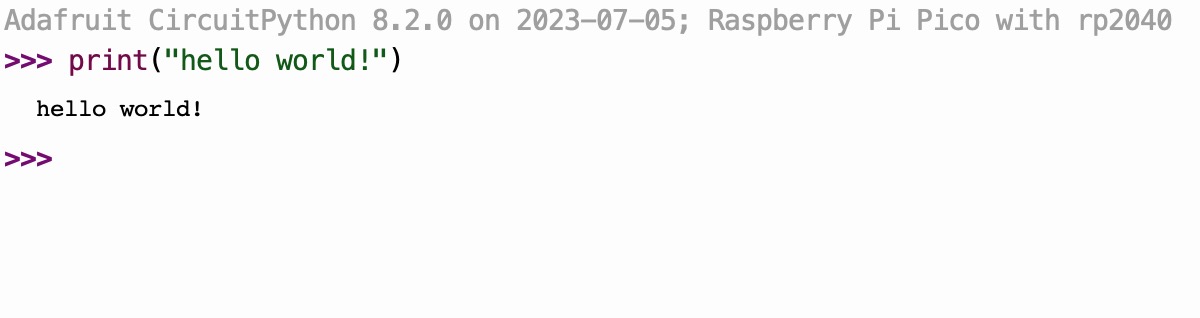
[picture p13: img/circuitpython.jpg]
circuitpython

11. 运行如下测试代码

>代码作用:查看SPI FLASH大小
```
import os

stat = os.statvfs('/')
flash_size_bytes = stat[0] * stat[2]

flash_size_MB = flash_size_bytes / (1024 * 1024)
print('SPI Flash size:', flash_size_MB, 'MB')

```
返回结果:
```
Adafruit CircuitPython 8.2.0 on 2023-07-05; Raspberry Pi Pico with rp2040
>>> import os

stat = os.statvfs('/')
flash_size_bytes = stat[0] * stat[2]

flash_size_MB = flash_size_bytes / (1024 * 1024)
print('SPI Flash size:', flash_size_MB, 'MB')

SPI Flash size: 14.9688 MB
>>> 
```

12. 退出MINICOM
```
ctrl A Q
```

13. 重启RP2040(如果需要)
```
echo 136 > /sys/class/gpio/export
echo out > /sys/class/gpio/gpio136/direction
echo 0 > /sys/class/gpio/gpio136/value
sleep 1
echo 1 > /sys/class/gpio/gpio136/value
sleep 1
echo 136 > /sys/class/gpio/unexport
```

14. 操作RP2040进入DFU模式
```
echo 136 > /sys/class/gpio/export
echo 135 > /sys/class/gpio/export
echo out > /sys/class/gpio/gpio136/direction
echo out > /sys/class/gpio/gpio135/direction
echo 1 > /sys/class/gpio/gpio136/value
echo 1 > /sys/class/gpio/gpio135/value
echo 136 > /sys/class/gpio/unexport
echo 135 > /sys/class/gpio/unexport
```

#### 1.3.6 语音识别与交互驱动
离线文字转语音espeak
```
apt install espeak
```

### 1.4 玩法推荐

> 以下所有DEMO，若运行报错，可尝试git pull拉取最新代码。

#### 1.4.1 在ISP屏幕上显示系统信息
```
neofetch --off > /dev/tty1
```

#### 1.4.2 在ISP屏幕上显示图片
1. 安装`fbi`
```
apt install fbi
```
2. 显示图片
>这里，-a：这个选项会让 fbi 自动缩放图像，使其适应屏幕的大小。 -noverbose：这个选项告诉 fbi 在启动时不要显示任何冗长的信息或警告。 -d /dev/fb0 指定了帧缓冲设备，-T 1 指定了使用哪个虚拟终端，image.jpg 是要显示的图像的路径。
```
fbi -a -noverbose -d /dev/fb0 -T 1 image.jpg
```
如果要关闭可以键盘`esc`或`q`，或者直接杀死进程。       .
3.使用`ffmpeg`显示图片
```
#demo1(无缩放)
ffmpeg -i input.jpg -c:v rawvideo -pix_fmt rgb565le -f fbdev /dev/fb0

#demo2(自动缩放)
ffmpeg -i ../ILSVRC2012_val_00000003.JPEG -vf "scale='min(320,iw)':'min(240,ih)'" -c:v rawvideo -pix_fmt rgb565le -f fbdev /dev/fb0
```

#### 1.4.3 在ISP屏幕上视频播放

```
ffmpeg -re -i video2_h264.mp4 -c:v rawvideo -pix_fmt rgb565le -f fbdev /dev/fb0
```

#### 1.4.4 USB摄像头
>注意，由于F1C200S USB EndPoint不足，所以无法驱动USB摄像头。
1. 查看摄像头支持的输出格式
```
v4l2-ctl --list-formats
v4l2-ctl --list-formats-ext
```
```
root@xddcore-zero:/xddcore_toolbox/v4l2_cameara# v4l2-ctl --list-formats
ioctl: VIDIOC_ENUM_FMT
        Type: Video Capture

        [0]: 'MJPG' (Motion-JPEG, compressed)
        [1]: 'YUYV' (YUYV 4:2:2)
```
2. 捕获图像
```
fswebcam -d /dev/video0 -r 320x240 test.jpeg
ffmpeg -f v4l2 -s 640x480 -i /dev/video0 output.jpg
```

#### 1.4.5 本地音乐播放

**音频播放请先通过以下命令打开运放**:
```
echo 138 > /sys/class/gpio/export
echo out > /sys/class/gpio/gpio138/direction
echo 1 > /sys/class/gpio/gpio138/value
echo 138 > /sys/class/gpio/unexport
```
```
mplayer xxx.mp3

或

aplayer xxx.mp3
```

#### 1.4.6 网易云音乐播放音乐播放
```
musicbox
```

#### 1.4.7 6轴陀螺仪
```
#demo1
/xddcore_toolbox/mpu6050

#demo2
/xddcore_toolbox/mpu6050_game
```

#### 1.4.8 LVGL
```
#demo1
/xddcore_toolbox/zero_lvgl_port/demo/lvgl_fb_example

#demo2
/xddcore_toolbox/zero_lvgl_port/demo/lvgl_fb_heartrate
```

#### 1.4.9 RP2040编程

见上述RP2040驱动章节

需要注意:在发布镜像中，由于F1C200S USB Endpoint不足，且开启了USB HID设备，并且USB HUB会占用一定的EndPoint。所以(以Circuit Python为例):

1. `如果要对RP2040的disk进行操作，改写Code.py文件。`则需要将拨码开关配置为`1010 1010`（越过USB Hub进行通信）。
2. `如果要对RP2040的disk进行操作，且需要依赖USB串口的交互模式。`则需要在Linux Kernel Menuconfig中关闭USB HID驱动(或将USB HID驱动编译为模块)后，自行编译内核。
3. `如果要对RP2040的disk进行操作，且需要依赖USB串口的交互模式，且想快速完成rp2040编程的话。`则需要将拨码开关配置为`0101 1010`（F1C200S连接板载USB Hub，RP2040通过Type-C连接电脑）。

#### 1.4.10 智能助手(Chatgpt-3.5)
1. 编辑文件，并填入自己的OPENAI API密钥 
```
vim /xddcore_toolbox/Hello-Pinecone/Hello-Pinecone.py
```
2. 运行DEMO
```
python3 /xddcore_toolbox/Hello-Pinecone/Hello-Pinecone.py
```

#### 1.4.11 登陆月球模拟器
详情见https://github.com/xddcore/TinyLander-Linux-fb

运行DEMO:
```
/xddcore_toolbox/TinyLander-Linux-fb/TinyLander
```

> 如遇屏幕闪烁，请git pull重新拉取最新代码后，重新编译运行。

#### 1.4.12 NES模拟器
>游戏ROM下载地址:https://www.emulatorgames.net/roms/nintendo/

1. 安装依赖
```
apt install alsa-utils
apt install libasound2-dev
apt install zlib1g-dev
```

2. 拉取InfoNES源码
```
git clone https://github.com/xddcore/arm-NES-linux.git -b zero-InfoNES
```

3. 编译
```
cd arm-NES-linux/linux
make
```

>测试游戏包下载:https://github.com/xddcore/arm-NES-linux/releases/tag/NES_Game_Pack

4. 下载测试游戏
```
wget https://github.com/xddcore/arm-NES-linux/releases/download/NES_Test_Game/Super_Mario_Bros_3.nes
```

5. 运行游戏
```
/xddcore_toolbox/arm-NES-linux/linux/InfoNES ./Super_Mario_Bros_3.nes
```

#### 1.4.13 OpenNNA2.0神经网络框架

1.拉取源码
```
git clone https://github.com/xddcore/OpenNNA2.0.git
```

2.编译
```
cd OpenNNA2.0/platform/zero_linux_board/
#ls看一下，如有/build，则请先执行rm -rf build/
mkdir build
cd build
cmake ..
make
```

3.运行
```
#结果显示在cmd
ffmpeg -i ../ILSVRC2012_val_00000003.JPEG -vf "scale=w=320:h=240" -c:v rawvideo -pix_fmt rgb565le -f fbdev /dev/fb0
./core
#结果显示在isp屏幕
ffmpeg -i ../ILSVRC2012_val_00000003.JPEG -vf "scale=w=320:h=240" -c:v rawvideo -pix_fmt rgb565le -f fbdev /dev/fb0
./core > /dev/tty1
```

#### 1.4.14 搭建个人博客(Typecho)

运行博客四件套(Nginx+php+SQlite3+typecho+rathole)，怎么轻量化怎么来

1. **安装nginx**
```
apt install nginx
```

此步骤后会遇到报错```Nginx Error: [::1]:80 failed: Address family not supported by protocol [Solved]```

原因及解决方法:
```
 该错误消息表明该服务正在尝试在 IPv6 地址“ [::]:80 ”上启动，但由于地址系列不受支持而失败。这意味着该机器没有设置 IPv6 地址。您需要做的就是简单地编辑 Ngnix 配置文件来监听 IPv4 地址，如下所示。
```
1. 打开/etc/nginx/sites-enabled/default
```
vim /etc/nginx/sites-enabled/default
```

2. 注释以下行：
```
listen [::]:80 default_server;
```

3. 重新运行安装
```
apt install nginx
```

4. 检查nginx运行状态
```
systemctl status nginx
```

5. 浏览器输入IP地址，再次检查Nginx是否运行正常

2. **安装PHP(内含mysql，sqlite等插件)**
```
apt install php7.3-cli php7.3-fpm php7.3-curl php7.3-mysql php7.3-gd php7.3-xml php7.3-mbstring php-sqlite3
```

3. **安装SQlite3**
```
apt install sqlite3 php-sqlite3
```

4. **修改/etc/nginx/sites-enabled/default(如下图)**
```
vim /etc/nginx/sites-enabled/default
```
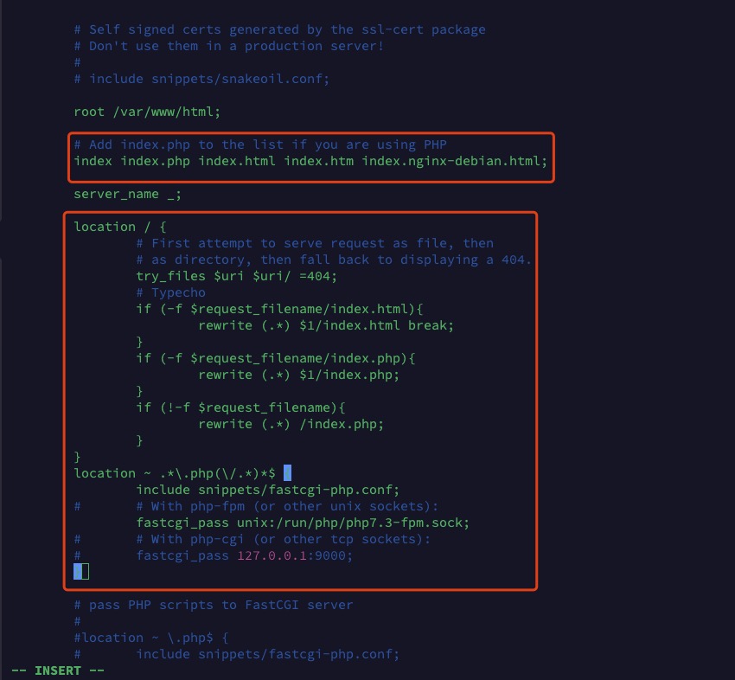
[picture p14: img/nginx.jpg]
Nginx配置修改

5. **重启nginx**
```
service nginx restart
```

6. **下载`Typecho`(地址:https://typecho.org/download)**
```
cd /var/www/html/
wget https://github.com/typecho/typecho/releases/latest/download/typecho.zip
unzip typecho.zip
rm typecho.zip
```

7. **将上传目录修改为可写入**
```
pwd=/var/www/html
chmod -R 777 ./
```

8. **访问开发板的IP地址**
```
ifconfig
```

9. **按照提示安装Typecho**
注意:数据库驱动请选择 pdo sqlite驱动        
后台:http://开发板IP地址/admin/      

10. Enjoy it!

#### 1.4.15 内网穿透(Rathole)
对于没有公网IP的场景，我们还需要一个内网穿透软件。最终选择`Rathole`(相比frpc`70MB`的内存占用来说，Rathole的内存占用仅`10MB`左右，非常适合部署在zero linux board中)。       

Rathole基于rust开发，官方并没有提供基于armv5tejl的二进制构建文件。所以我们需要手动交叉编译。(万幸，armv5tejl在rust的第二层支持列表中)            

所有服务运行起来后的系统资源信息:
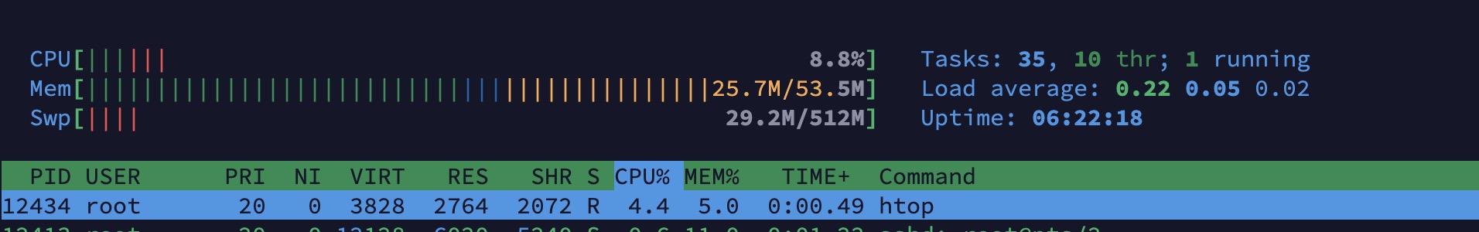
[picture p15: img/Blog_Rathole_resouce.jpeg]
Typeho+Rathole资源占用


**以下为在交叉编译环境中的操作**
1. 安装rust
```
curl --proto '=https' --tlsv1.2 -sSf https://sh.rustup.rs | sh
```

2. 安装交叉编译工具链
```
sudo apt-get install -qq gcc-arm-linux-gnueabi
sudo apt-get install gcc-arm-linux-gnueabi libc6-armel-cross libc6-dev-armel-cross
 sudo apt install pkg-config
 sudo apt install libssl-dev
 sudo apt-get install libudev-dev
 sudo apt install librust-openssl-sys-dev
 sudo apt install perl

export OPENSSL_DIR="usr/lib/ssl"
export OPENSSL_INCLUDE_DIR="/usr/include/openssl"
export OPENSSL_LIB_DIR="/usr/lib/x86_64-linux-gnu"
```
3. 添加目标

```
rustup target add armv5te-unknown-linux-gnueabi

```

4. 配置cargo
```
$ mkdir -p ~/.cargo
$ vim ~/.cargo/config
#添加以下内容:
[target.armv5te-unknown-linux-gnueabi]
linker = "arm-linux-gnueabi-gcc"

```
5. 拉取rathole源码
```
git clone https://github.com/rapiz1/rathole.git
cd rathole/
git checkout tags/v0.4.8
```
6. 编译源码
```
cargo build --release --target armv5te-unknown-linux-gnueabi \
  --no-default-features --features noise,client,server,hot-reload \
  --config target.armv5te-unknown-linux-gnueabi.linker=\"rust-lld\"

  cargo build --release --target armv5te-unknown-linux-gnueabi \
  --no-default-features --features noise,client,server,hot-reload \
  --config target.armv5te-unknown-linux-gnueabi.linker=\"arm-linux-gnueabi-gcc\"
```

7. 编译好的二进制文件在`rathole/target/armv5te-unknown-linux-gnueabi/release`目录下

**服务器部署**
1. 下载构建好的二进制文件
```
wget https://github.com/rapiz1/rathole/releases/download/v0.4.8/rathole-x86_64-unknown-linux-gnu.zip
```
2. 创建并编辑配置文件
```
vim server.toml

#填入以下内容
# server.toml
[server]
bind_addr = "0.0.0.0:2333" # `2333` 配置了服务端监听客户端连接的端口
[server.services.my_blog]
token = "123456" # 用于验证的 token
bind_addr = "0.0.0.0:80" # `5202` 配置了将 `my_blog` 暴露给互联网的端口
```
3. 运行rothole
```
./rothole server.toml
```

**客户端部署(即Zero Linux Board)**
1. 下载构建好的二进制文件
```
wget https://github.com/xddcore/Zero_Linux_Board/releases/download/Rathole_Armv5tejl/rathole
```
2. 创建并编辑配置文件
```
vim client.toml

#填入以下内容
# client.toml
[client]
remote_addr = "myserver.com:2333" # 服务器的地址。端口必须与 `server.bind_addr` 中的端口相同。
[client.services.my_nas_ssh]
token = "use_a_secret_that_only_you_know" # 必须与服务器相同以通过验证
local_addr = "127.0.0.1:22" # 需要被转发的服务的地址
```
3. 运行rothole
```
./rothole client.toml
```

## 1.5 一些图片
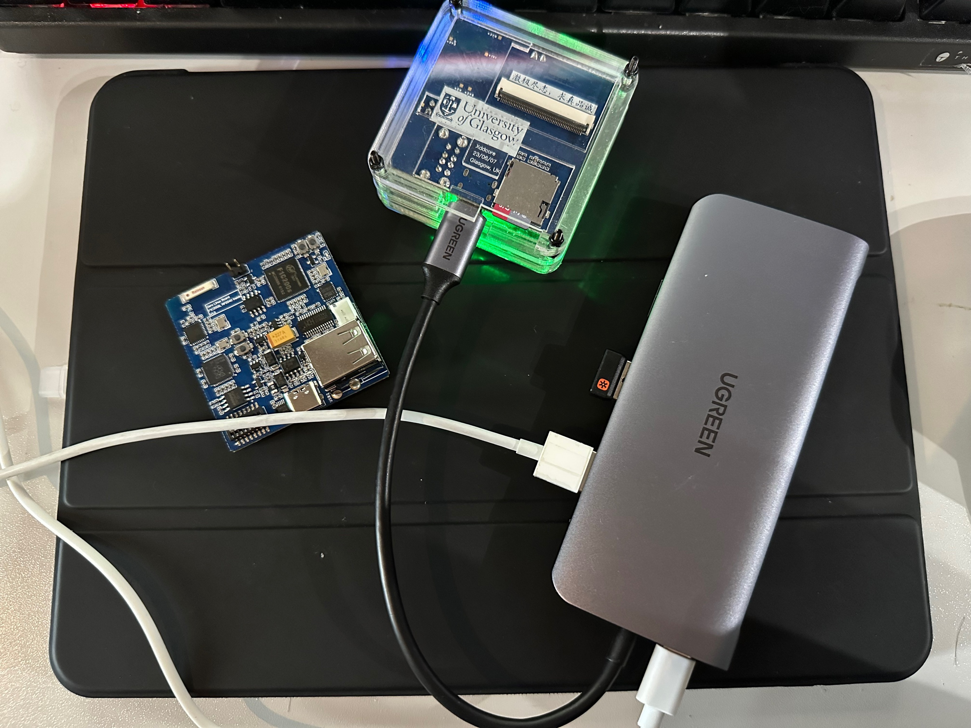
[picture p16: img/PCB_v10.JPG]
PCB_v10

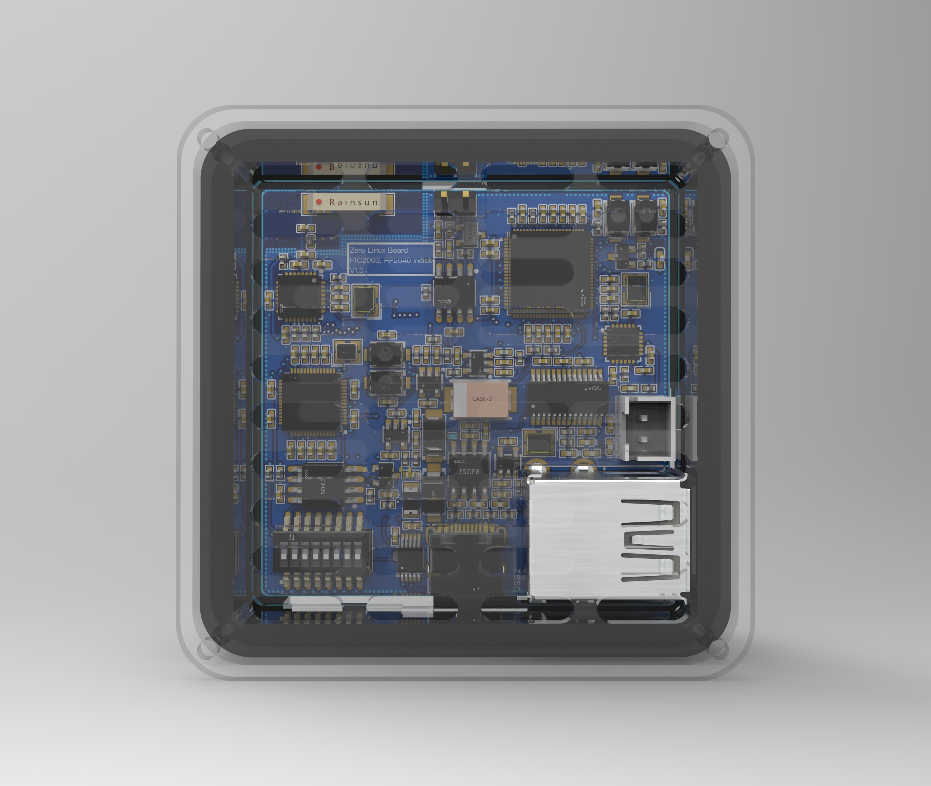
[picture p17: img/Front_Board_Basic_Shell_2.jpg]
Front_Board_Basic_Shell_2

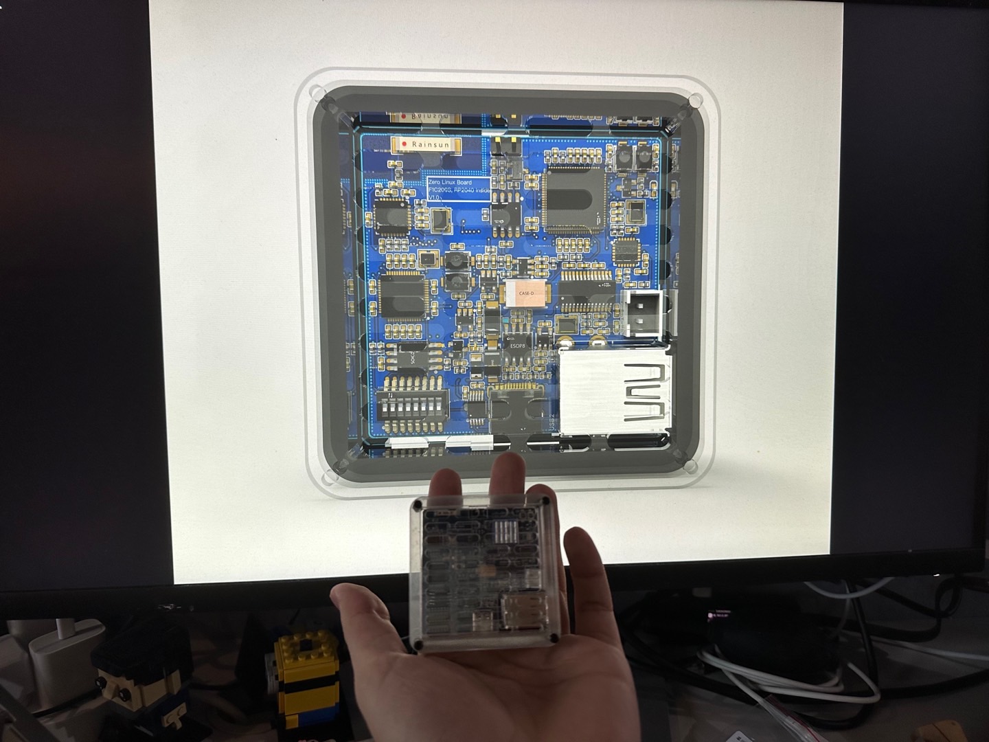
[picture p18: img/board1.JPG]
board1

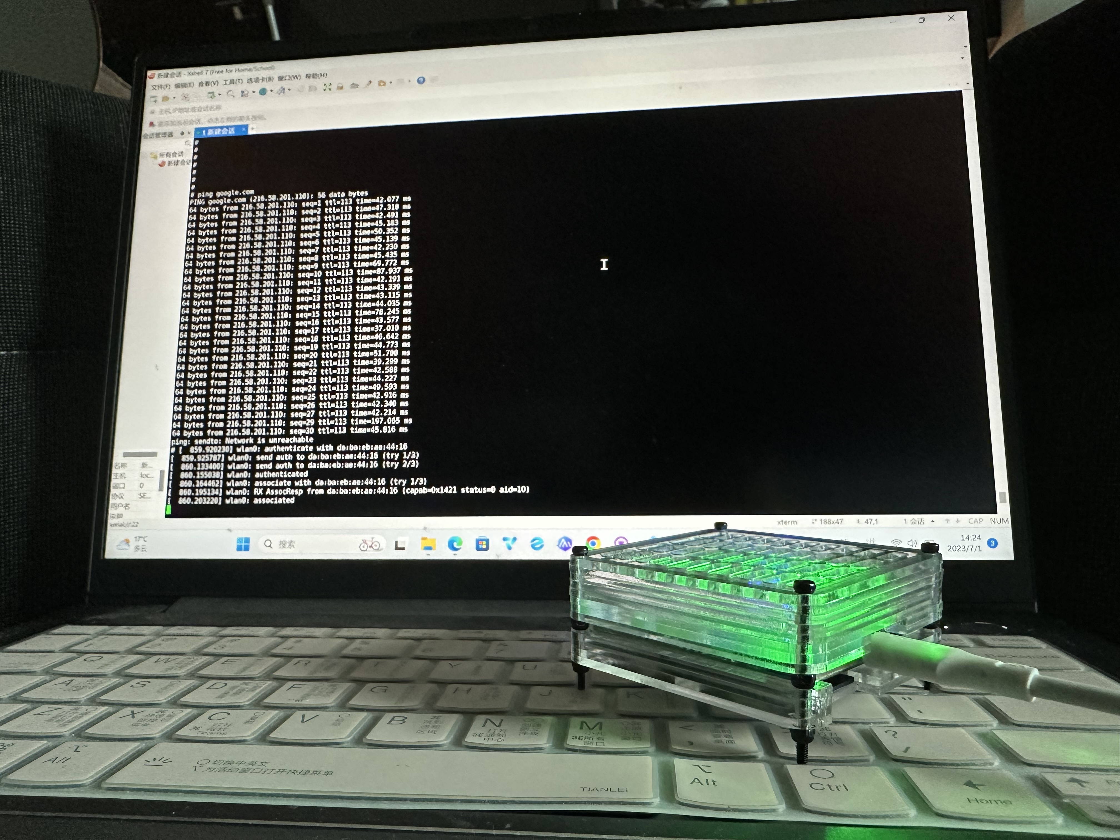
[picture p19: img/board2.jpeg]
board2

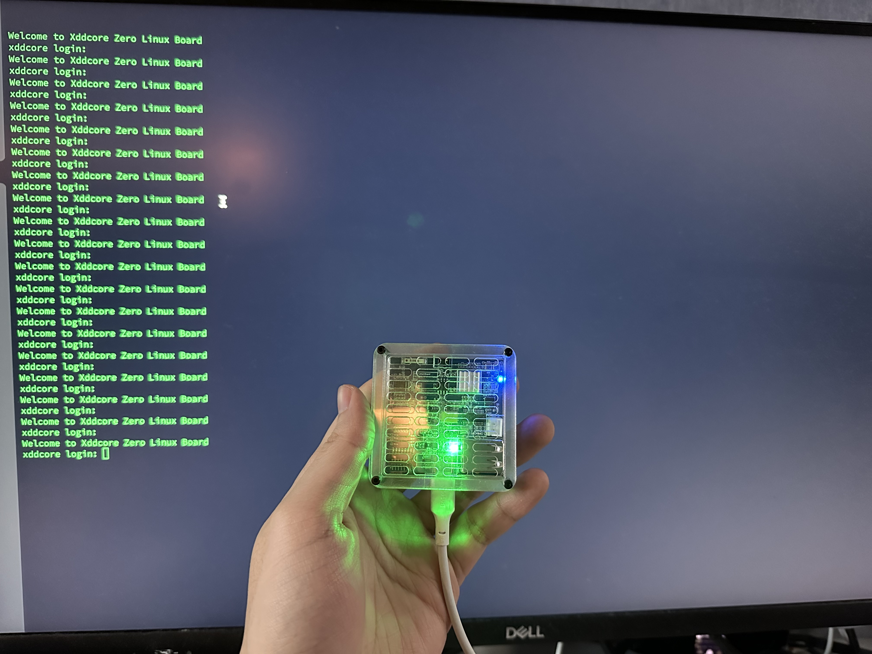
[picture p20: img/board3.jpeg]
board3

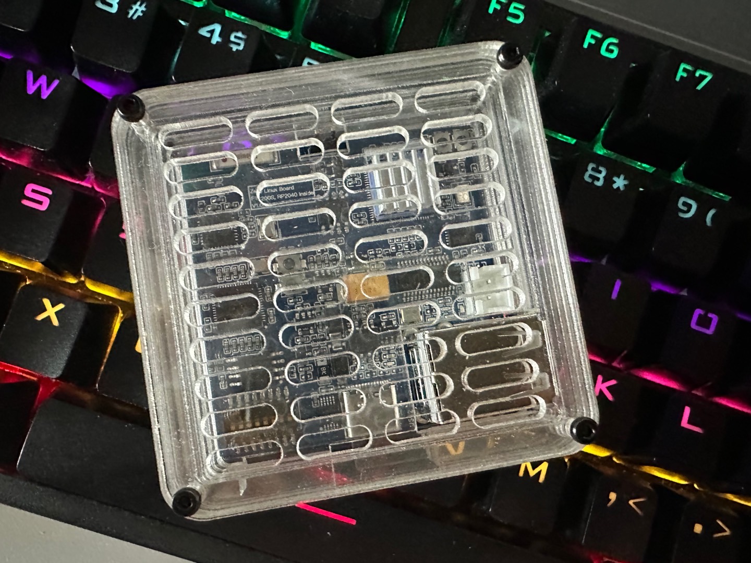
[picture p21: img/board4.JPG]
board4

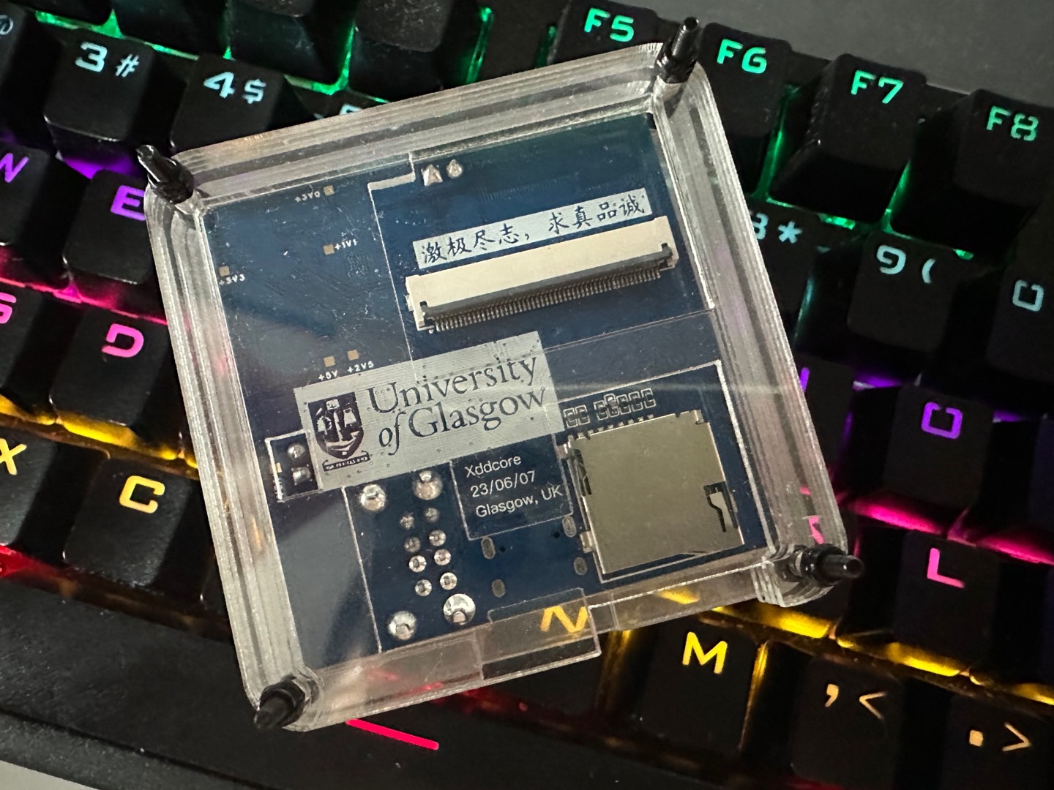
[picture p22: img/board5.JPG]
board5


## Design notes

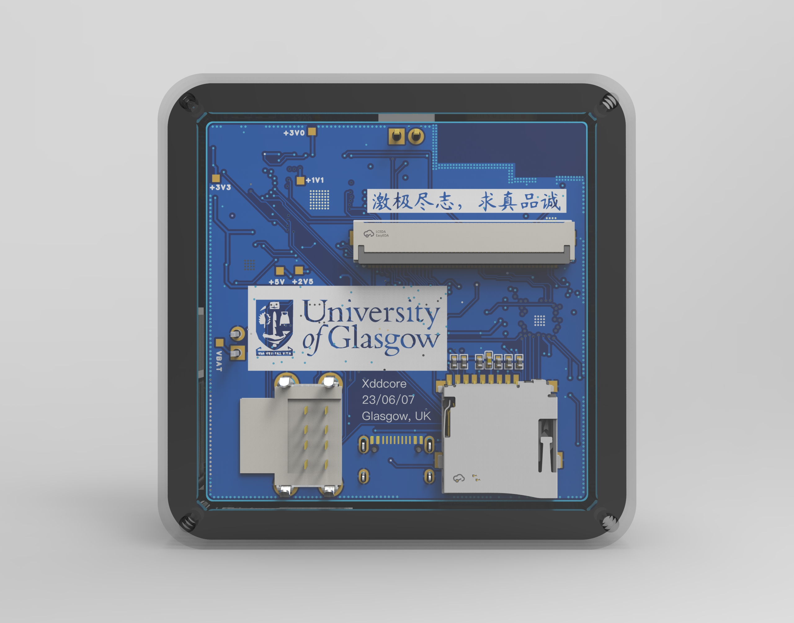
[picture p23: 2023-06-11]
1.Hardware/1.1Zero_Linux_Board/SHELL_EXPLORE/Explore-2.jpg

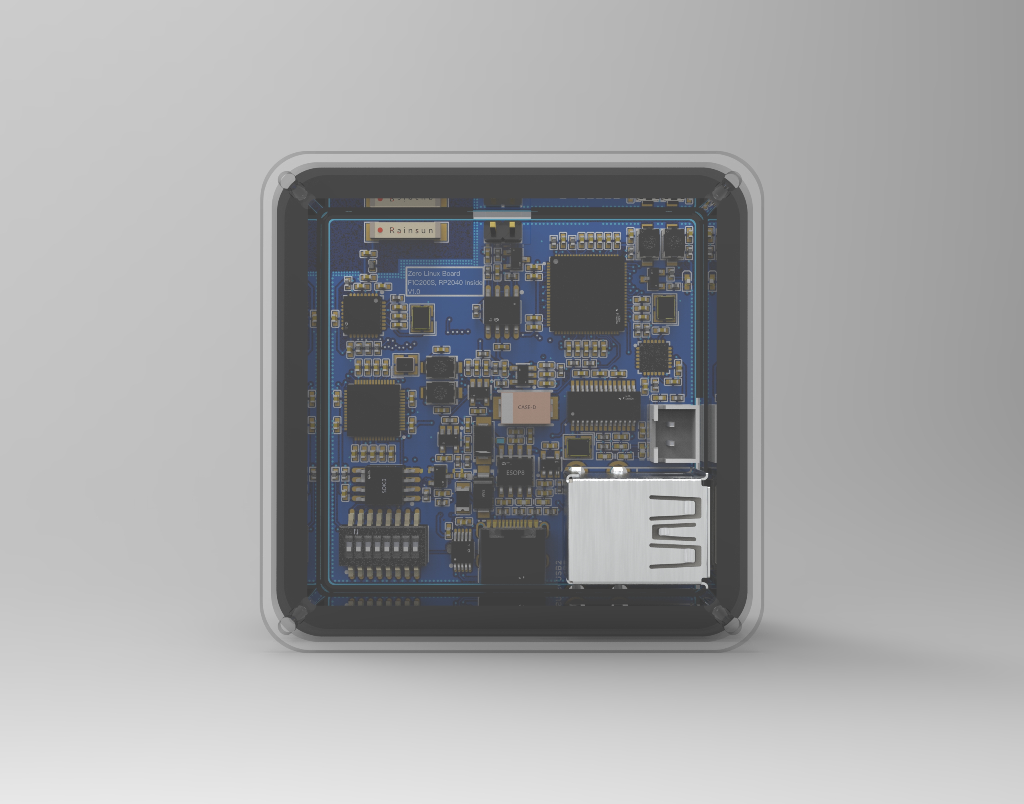
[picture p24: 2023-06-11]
1.Hardware/1.1Zero_Linux_Board/SHELL_EXPLORE/Explore-1.jpg

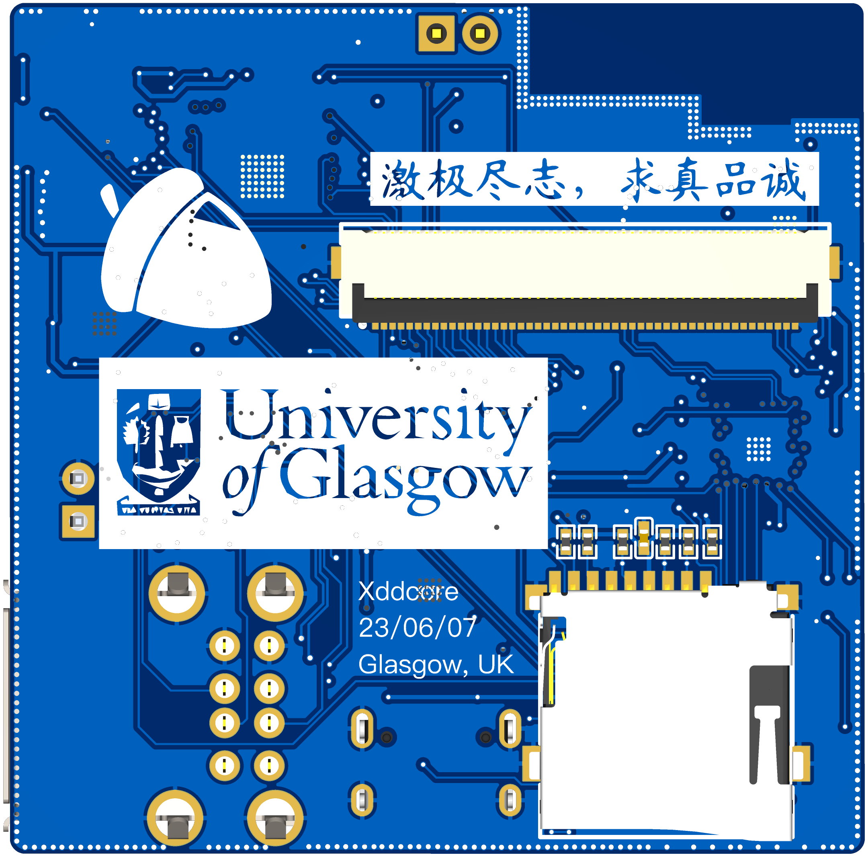
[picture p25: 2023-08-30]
1.Hardware/1.2Zero_Linux_Board_Production/JLCEDA/Bottom_3D_Zero_PCB_2023-07-22.png

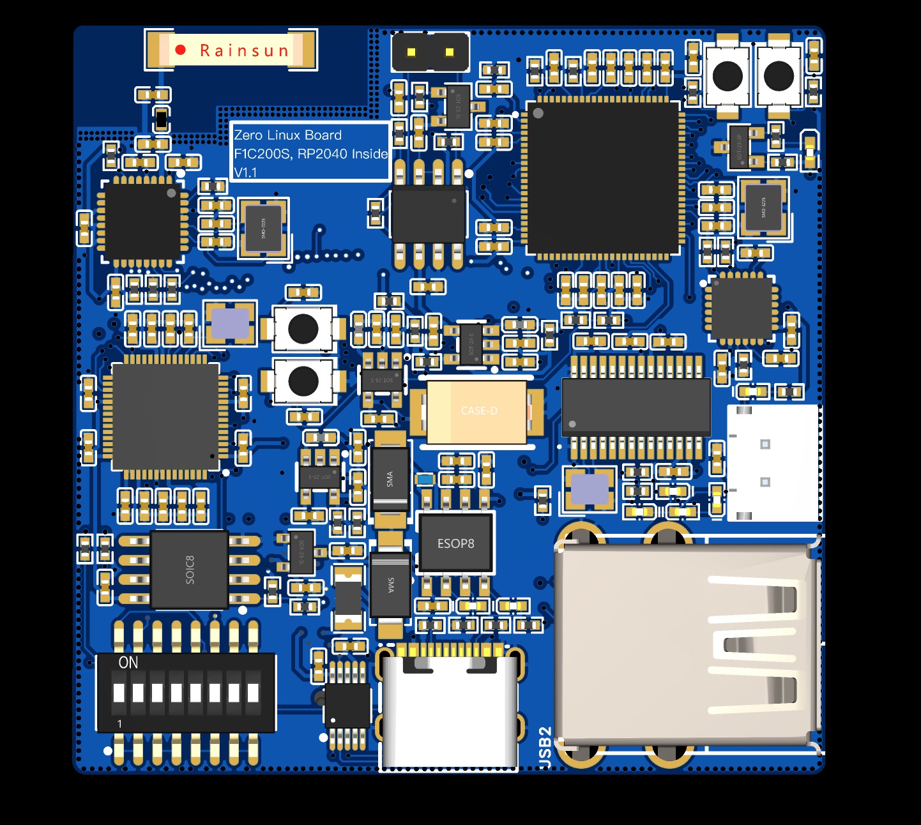
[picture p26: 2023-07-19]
1.Hardware/1.1Zero_Linux_Board/JLCEDA/PCB_TOP.jpeg

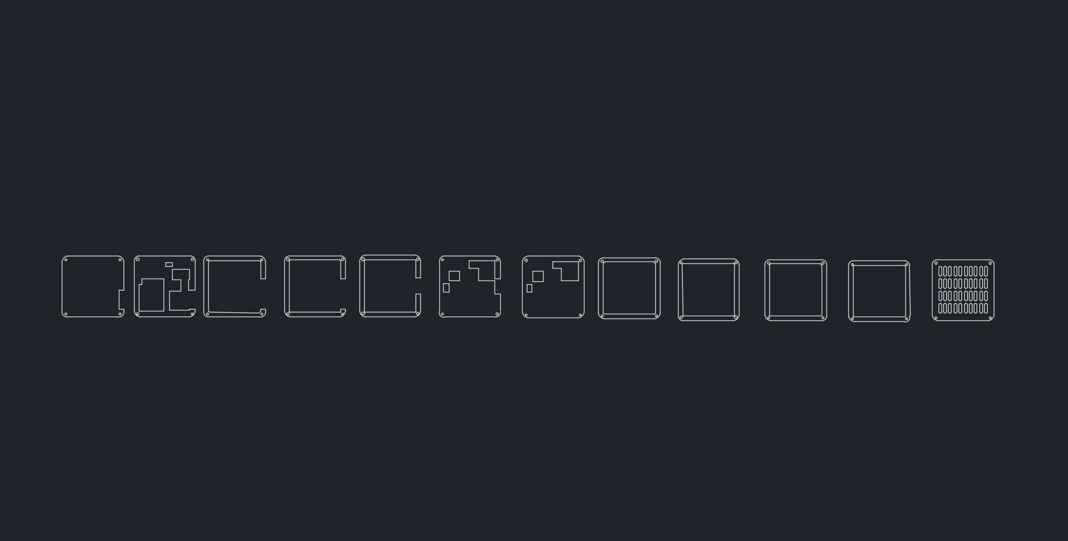
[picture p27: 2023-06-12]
1.Hardware/1.1Zero_Linux_Board/SHELL_BASIC/dwg_1.jpeg

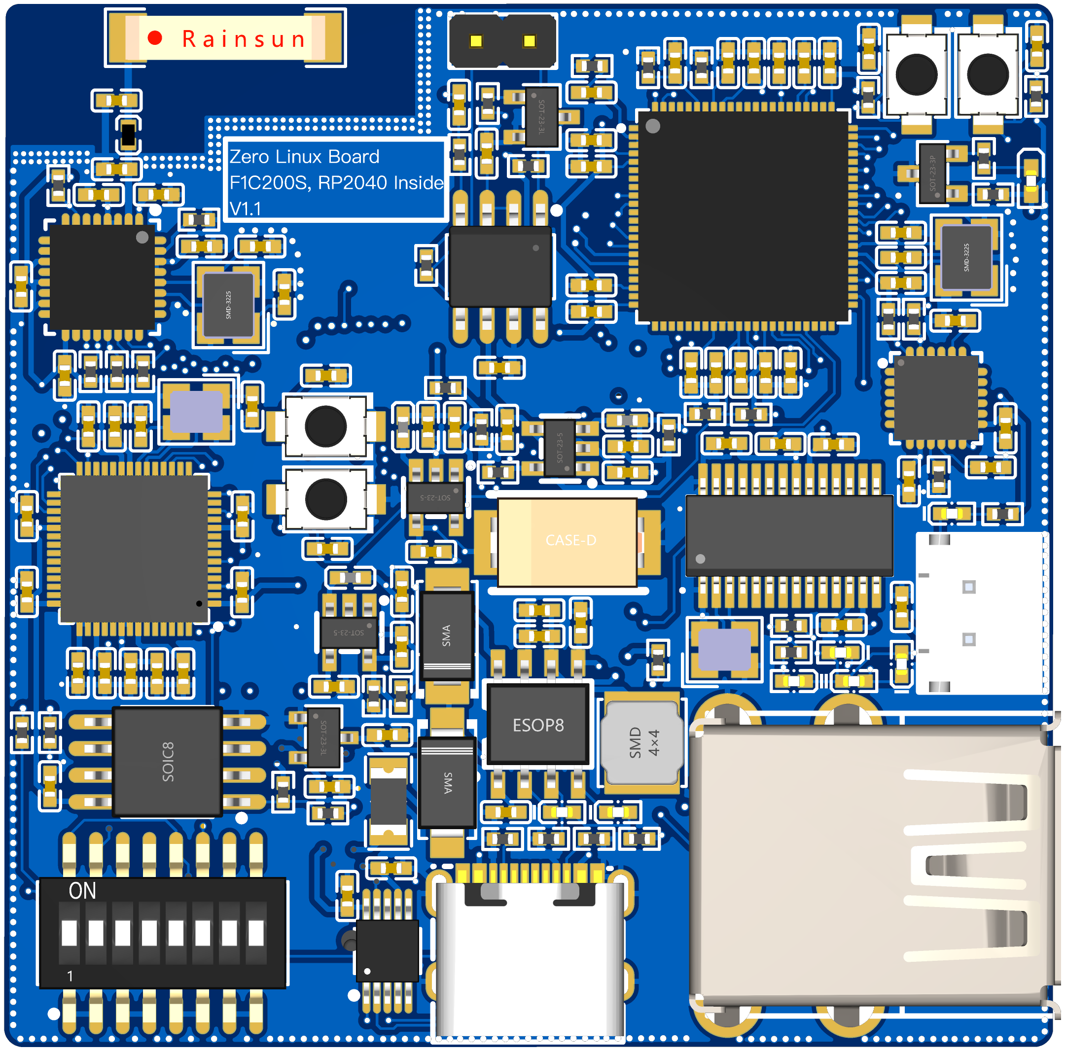
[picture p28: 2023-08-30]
1.Hardware/1.2Zero_Linux_Board_Production/JLCEDA/3D_Zero_PCB_2023-07-22.png

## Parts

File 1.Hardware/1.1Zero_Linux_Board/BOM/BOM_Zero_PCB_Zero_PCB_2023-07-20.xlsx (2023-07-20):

No. | Quantity | Comment | Designator | Footprint | Value | Manufacturer Part | Manufacturer | Supplier Part | Supplier
1 | 40 | 100nF | C79,C80,C94,C96,C99,C100,C101,C102,C103,C104,C105,C106,C107,C108,C111,C112,C113,C114,C117,C118,C121,C128,C129,C132,C134,C136,C137,C142,C146,C149,C150,C151,C152,C153,C154,C155,C156,C157,C158,C159 | C0402 | 100nF | 0402B104K160NT | FH(风华) | C41851 | LCSC
2 | 9 | 10uF | C82,C84,C85,C87,C88,C90,C93,C120,C141 | C0402 | 10uF | CL05A106MQ5NUNC | SAMSUNG(三星) | C15525 | LCSC
3 | 3 | 20pF | C83,C86,C89 | C0402 | 20pF | 0402CG200J500NT | FH(风华) | C1554 | LCSC
4 | 10 | 1uF | C91,C92,C115,C116,C122,C123,C139,C140,C160,C161 | C0402 | 1uF | CL05A105KP5NNNC | SAMSUNG(三星) | C14445 | LCSC
5 | 1 | 220uF | C95 | CASE-D_7343 | 220uF | TAJD227K010RNJ | Kyocera AVX | C8024 | LCSC
6 | 2 | 22uF | C97,C98 | C0402 | 22uF | GRM155R60J226ME11D | muRata(村田) | C415703 | LCSC
7 | 2 | 18pF | C109,C110 | C0402 | 18pF | 0402CG180J500NT | FH(风华) | C1549 | LCSC
8 | 1 | 390nF | C124 | C0402 | 390nF | GRM155R61A394KE15D | muRata(村田) | C350937 | LCSC
9 | 1 | 3pF | C125 | C0402 | 3pF | 0402CG3R0C500NT | FH(风华) | C1564 | LCSC
10 | 1 | 2.4pF | C127 | C0402 | 2.4pF | GJM1555C1H2R4WB01D | muRata(村田) | C88889 | LCSC
11 | 2 | 10pF | C130,C131 | C0402 | 10pF | CL05C100JB5NNNC | SAMSUNG(三星) | C32949 | LCSC
12 | 1 | 10nF | C133 | C0402 | 10nF | CL05B103KB5NNNC | SAMSUNG(三星) | C15195 | LCSC
13 | 1 | 2.2nF | C135 | C0402 | 2.2nF | 0402B222K500NT | FH(风华) | C1531 | LCSC
14 | 2 | 27pF | C147,C148 | C0402 | 27pF | 0402CG270J500NT | FH(风华) | C1557 | LCSC
15 | 1 | 100nF | C162 | C0402 | 100nF | CL05B104KO5NNNC | SAMSUNG(三星) | C1525 | LCSC
16 | 1 | TF-01A | CARD1 | TF-SMD_TF-01A |  | TF-01A | 韩国韩荣 | C91145 | LCSC
17 | 1 | SS54 | D1 | SMA_L4.4-W2.8-LS5.4-R-RD | SS54 | SS54 | MDD | C22452 | LCSC
18 | 1 | SS32 | D11 | SMA_L4.3-W2.6-LS5.2-RD |  | SS32 | MDD | C34897 | LCSC
19 | 1 | BSMD1206-200-6V | F1 | F1206 | Fuse | BSMD1206-200-6V | BHFUSE(佰宏) | C883134 | LCSC
20 | 1 | FPC-05FB-50PH20 | FPC1 | FPC-SMD_50P-P0.50_FPC-05FB-50PH20 |  | FPC-05FB-50PH20 | XUNPU(讯普) | C2856838 | LCSC
21 | 1 | PZ254V-11-02P | H1 | HDR-TH_2P-P2.54-V-M |  | PZ254V-11-02P | XFCN(兴飞) | C492401 | LCSC
22 | 1 | HX25003-2A | J1 | CONN-TH_2P-P2.50_HX25003-2A | Conn_01x02 | HX25003-2A | HX(红星) | C442299 | LCSC
23 | 3 | 2.2uH | L5,L6,L7 | L0402 | 2.2uH | SDFL1005P2R2KTF | Sunlord(顺络) | C49067 | LCSC
24 | 1 | 10uH | L8 | IND-SMD_L1.0-W0.5-2 | 10uH | LQW15DN100M00D | muRata(村田) | C910650 | LCSC
25 | 1 | 2.2nH | L10 | IND-SMD_L1.0-W0.6 | 2.2nH | LQW15AN2N2C10D | muRata(村田) | C91240 | LCSC
26 | 1 | AN9520-245 | L11 | ANT-SMD_L9.5-W2.1 |  | AN9520-245 | rainsun(霖昱微) | C99665 | LCSC
27 | 1 | NCD0402R1 | LED1 | LED0402-RD |  | NCD0402R1 | 国星光电 | C130719 | LCSC
28 | 6 | XL-1005UGC | LED2,LED4,LED5,LED6,LED7,LED8 | LED0402-RD_GREEN |  | XL-1005UGC | XINGLIGHT(成兴光) | C2856703 | LCSC
29 | 1 | NCD0402B1 | LED3 | LED0402-R-RD |  | NCD0402B1 | 国星光电 | C130724 | LCSC
30 | 1 | 2N7002 | Q1 | SOT-23-3_L2.9-W1.3-P1.90-LS2.4-BR |  | 2N7002 | CJ(江苏长电/长晶) | C8545 | LCSC
31 | 1 | S8050 | Q2 | SOT-23-3_L2.9-W1.6-P1.90-LS2.8-BR |  | S8050 | CJ(江苏长电/长晶) | C105433 | LCSC
32 | 4 | 2.2kΩ | R58,R59,R68,R69 | R0402 | 2.2kΩ | 0402WGF2201TCE | UNI-ROYAL(厚声) | C25879 | LCSC
33 | 1 | 680kΩ | R60 | R0402 | 680kΩ | RC0402FR-07680KL | YAGEO(国巨) | C163456 | LCSC
34 | 4 | 150kΩ | R61,R63,R64,R65 | R0402 | 150kΩ | 0402WGF1503TCE | UNI-ROYAL(厚声) | C25755 | LCSC
35 | 1 | 470kΩ | R62 | R0402 | 470kΩ | 0402WGF4703TCE | UNI-ROYAL(厚声) | C25790 | LCSC
36 | 1 | 1.1kΩ | R66 | R0402 | 1.1kΩ | 0402WGF1101TCE | UNI-ROYAL(厚声) | C25860 | LCSC
37 | 3 | 1kΩ | R67,R77,R101 | R0402 | 1kΩ | 0402WGJ0102TCE | UNI-ROYAL(厚声) | C25543 | LCSC
38 | 2 | 200kΩ | R70,R71 | R0402 | 200kΩ | 0402WGF2003TCE | UNI-ROYAL(厚声) | C25764 | LCSC
39 | 3 | 49.9kΩ | R72,R73,R75 | R0402 | 49.9kΩ | 0402WGF4992TCE | UNI-ROYAL(厚声) | C25897 | LCSC
40 | 1 | 3.3kΩ | R74 | R0402 | 3.3kΩ | 0402WGF3301TCE | UNI-ROYAL(厚声) | C25890 | LCSC
41 | 14 | 10kΩ | R76,R80,R81,R82,R84,R85,R88,R89,R90,R91,R92,R93,R100,R108 | R0402 | 10kΩ | 0402WGF1002TCE | UNI-ROYAL(厚声) | C25744 | LCSC
42 | 2 | 20kΩ | R78,R79 | R0402 | 20kΩ | 0402WGF2002TCE | UNI-ROYAL(厚声) | C25765 | LCSC
43 | 1 | 12kΩ | R83 | R0402 | 12kΩ | 0402WGF1202TCE | UNI-ROYAL(厚声) | C25752 | LCSC
44 | 2 | 4.7kΩ | R86,R87 | R0402 | 4.7kΩ | 0402WGF4701TCE | UNI-ROYAL(厚声) | C25900 | LCSC
45 | 2 | 27Ω | R102,R103 | R0402 | 27Ω | 0402WGJ0270TCE | UNI-ROYAL(厚声) | C25156 | LCSC
46 | 2 | 220Ω | R104,R105 | R0402 | 220Ω | 0402WGF2200TCE | UNI-ROYAL(厚声) | C25091 | LCSC
47 | 1 | 470Ω | R106 | R0402 | 470Ω | 0402WGF4700TCE | UNI-ROYAL(厚声) | C25117 | LCSC
48 | 1 | 22Ω | R107 | R0402 | 22Ω | 0402WGF220JTCE | UNI-ROYAL(厚声) | C25092 | LCSC
49 | 1 | DSHP08TS-S | SW1 | SW-SMD_DSHP08TS-S |  | DSHP08TS-S | XKB Connectivity(中国星坤) | C319047 | LCSC
50 | 4 | TS-1088-AR02016 | SW2,SW3,SW4,SW5 | SW-SMD_L3.9-W3.0-P4.45 |  | TS-1088-AR02016 | XUNPU(讯普) | C720477 | LCSC
51 | 3 | SY8088AAC | U1,U16,U17 | SOT-23-5_L3.0-W1.7-P0.95-LS2.8-BR | SY8088AAC | SY8088AAC | silergy(矽力杰) | C79313 | LCSC
52 | 1 | XC6206P302MR | U4 | SOT-23-3_L3.0-W1.7-P0.95-LS2.9-BR | XC6206P302MR | XC6206P302MR | HXY MOSFET(华轩阳电子) | C5148691 | LCSC
53 | 1 | TP5400 | U5 | ESOP-8_L4.9-W3.9-P1.27-LS6.0-BL-EP | TP5400 | TP5400 | TOPPOWER(南京拓微) | C2891434 | LCSC
54 | 1 | CH340E | U6 | MSOP-10_L3.0-W3.0-P0.50-LS5.0-BL | CH340E | CH340E | WCH(南京沁恒) | C99652 | LCSC
55 | 1 | F1C200S | U18 | QFN-88_L10.0-W10.0-P0.40-BL-EP6.75 |  | F1C200S | Allwinner(全志) | C2879851 | LCSC
56 | 1 | 24MHz | U19 | CRYSTAL-SMD_4P-L3.2-W2.5-BL | 24MHz | XXHCCLNANF-24MHZ | TAITIEN(泰艺电子) | C5160135 | LCSC
57 | 1 | LM4871DRG | U20 | SOP-8_L4.9-W3.9-P1.27-LS6.0-BL |  | LM4871DRG | HGC(深圳汉芯) | C2977084 | LCSC
58 | 1 | ESP8266EX | U22 | QFN-32_L5.0-W5.0-P0.50-BL-EP3.7 |  | ESP8266EX | ESPRESSIF(乐鑫) | C77967 | LCSC
59 | 1 | MPU-6050 | U23 | QFN-24_L4.0-W4.0-P0.50-BL-EP2.7 |  | MPU-6050 | TDK InvenSense(应美盛) | C24112 | LCSC
60 | 1 | CH334U | U24 | QSOP-28_L9.9-W3.9-P0.64-LS6.0-BL |  | CH334U | WCH(南京沁恒) | C5187524 | LCSC
61 | 1 | RP2040 | U25 | LQFN-56_L7.0-W7.0-P0.4-EP |  | RP2040 | Raspberry Pi(树莓派) | C2040 | LCSC
62 | 1 | W25Q128JVSIQ | U28 | SOIC-8_L5.3-W5.3-P1.27-LS8.0-BL |  | W25Q128JVSIQ | WINBOND(华邦) | C97521 | LCSC
63 | 1 | U262-161N-4BVC11 | UART1 | USB-3.1-SMD_U262-161N-4BVC11 | USB_C | U262-161N-4BVC11 | XKB Connectivity(中国星坤) | C319148 | LCSC
64 | 1 | 907-112A1012D10200 | USB2 | USB-A-TH_USB-M-51 |  | 907-112A1012D10200 | 精拓金 | C39469 | LCSC
65 | 1 | 26MHz | X1 | CRYSTAL-SMD_4P-L3.2-W2.5-BL | 26MHz | NX3225SA-26MHZ-STD-CQR-1 | NDK | C156251 | LCSC
66 | 1 | - | X2 | OSC-SMD_4P-L2.5-W2.0-BL | - | XYDBPCNANF-12MHZ | TAITIEN(泰艺电子) | C521567 | LCSC
67 | 1 | 12MHz | X3 | OSC-SMD_4P-L2.5-W2.0-BL | - | XYDBPCNANF-12MHZ | TAITIEN(泰艺电子) | C521567 | LCSC

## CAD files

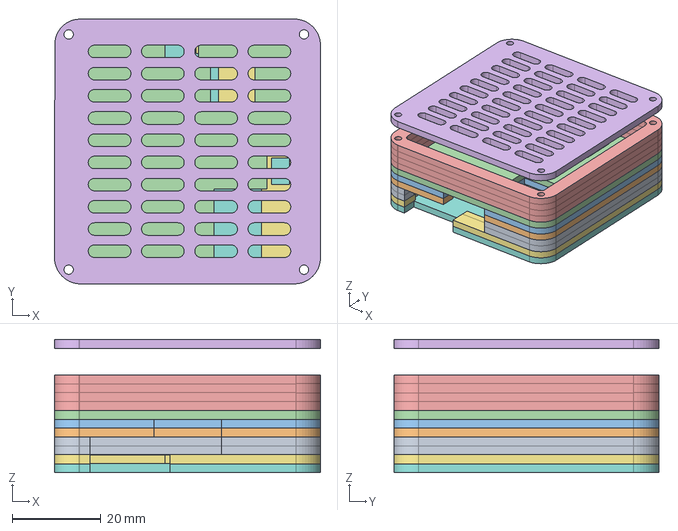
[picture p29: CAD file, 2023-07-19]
1.Hardware/1.1Zero_Linux_Board/SHELL_BASIC/3D_Zero_PCB_2023-06-11 v10(仅有外壳).step
59.9 x 59.7 x 30.0 mm

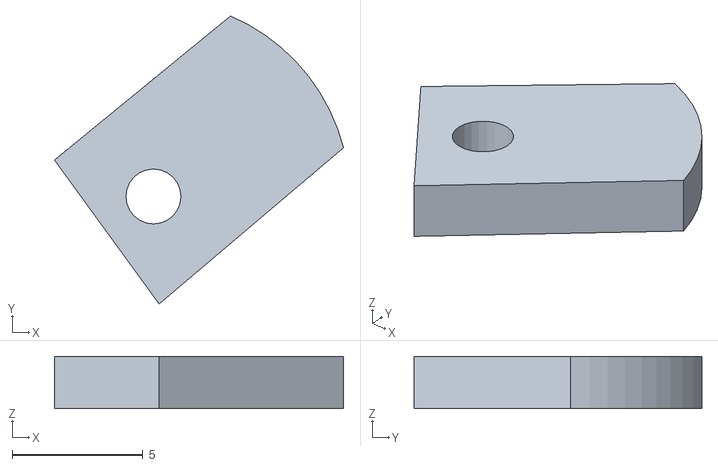
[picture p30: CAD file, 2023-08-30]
1.Hardware/1.3MINI_PC_Board/MINI_PC_SHELL/STL/BiliBiliTV v71-扩展版固定扣1.stl
11.0 x 11.0 x 2.00

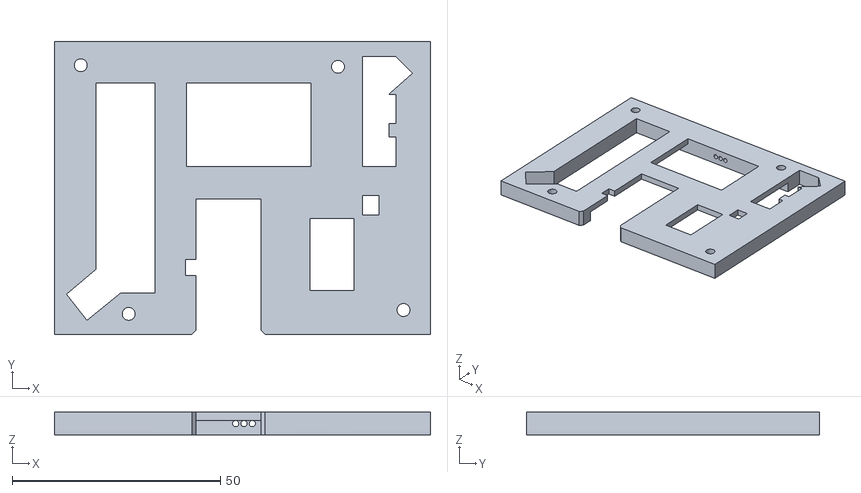
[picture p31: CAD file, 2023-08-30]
1.Hardware/1.3MINI_PC_Board/MINI_PC_SHELL/STL/BiliBiliTV v76-外壳2.stl
90.2 x 70.3 x 5.40

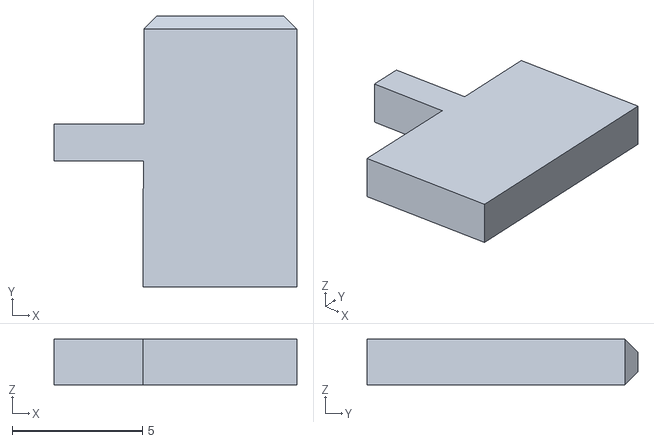
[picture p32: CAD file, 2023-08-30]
1.Hardware/1.3MINI_PC_Board/MINI_PC_SHELL/STL/BiliBiliTV v75-按钮3.stl
9.34 x 10.4 x 1.75

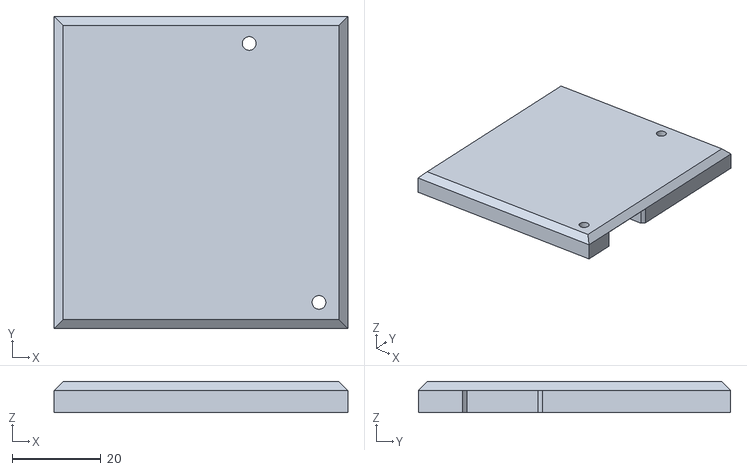
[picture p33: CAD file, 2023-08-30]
1.Hardware/1.3MINI_PC_Board/MINI_PC_SHELL/STL/BiliBiliTV v78-外壳4.stl
66.1 x 70.3 x 7.00

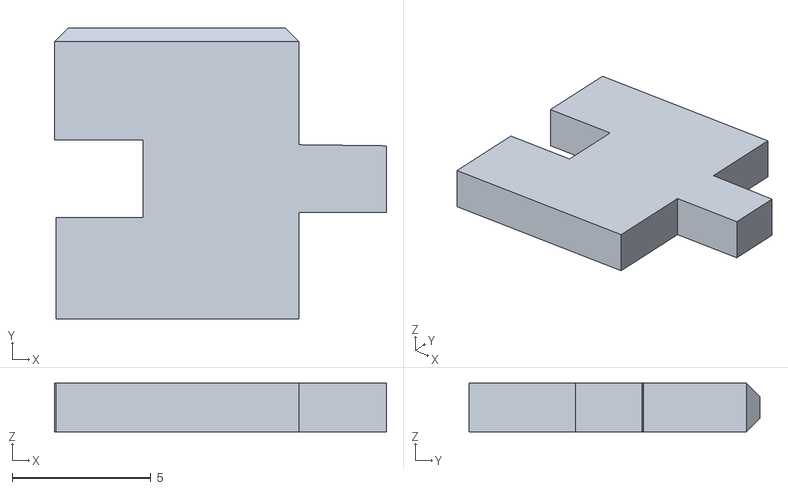
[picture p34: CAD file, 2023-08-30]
1.Hardware/1.3MINI_PC_Board/MINI_PC_SHELL/STL/BiliBiliTV v73-按钮1.stl
12.0 x 10.5 x 1.75

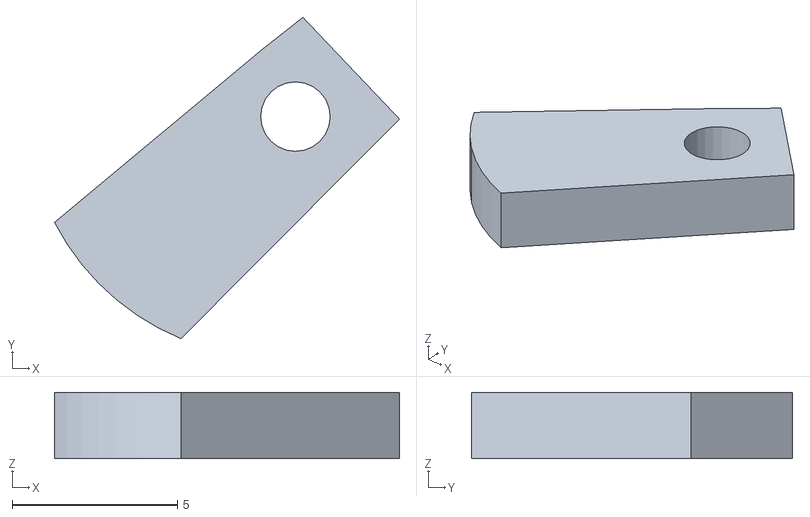
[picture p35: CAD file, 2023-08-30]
1.Hardware/1.3MINI_PC_Board/MINI_PC_SHELL/STL/BiliBiliTV v72-拓展版固定扣2.stl
10.4 x 9.71 x 2.00

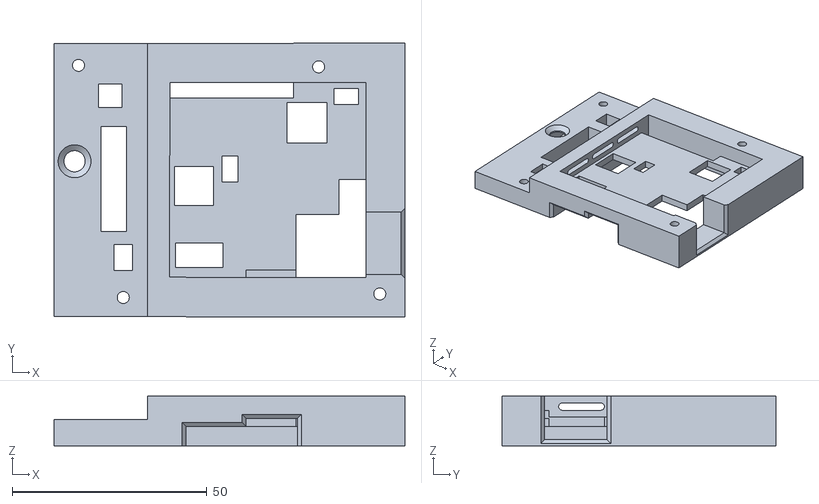
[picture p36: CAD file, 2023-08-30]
1.Hardware/1.3MINI_PC_Board/MINI_PC_SHELL/STL/BiliBiliTV v77-外壳3.stl
90.2 x 70.3 x 12.8

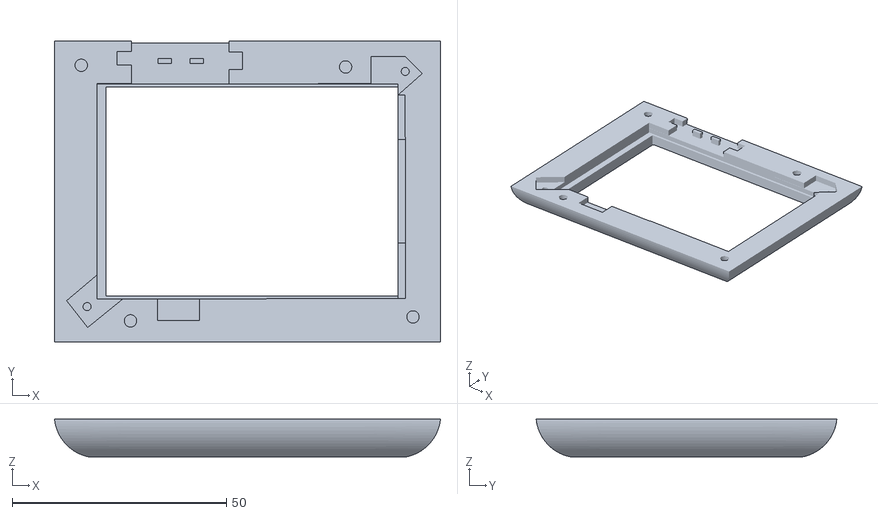
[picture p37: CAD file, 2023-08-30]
1.Hardware/1.3MINI_PC_Board/MINI_PC_SHELL/STL/BiliBiliTV v70-外壳1.stl
90.1 x 70.2 x 8.80

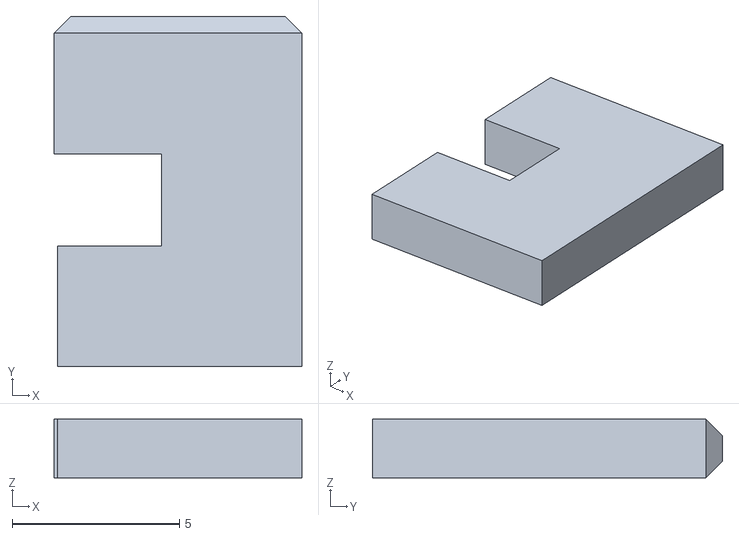
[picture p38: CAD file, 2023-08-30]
1.Hardware/1.3MINI_PC_Board/MINI_PC_SHELL/STL/BiliBiliTV v74-按钮2.stl
7.40 x 10.5 x 1.75

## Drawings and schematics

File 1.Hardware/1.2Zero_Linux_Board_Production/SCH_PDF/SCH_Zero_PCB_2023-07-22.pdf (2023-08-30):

USB | CPU0 F1C200S

## Power

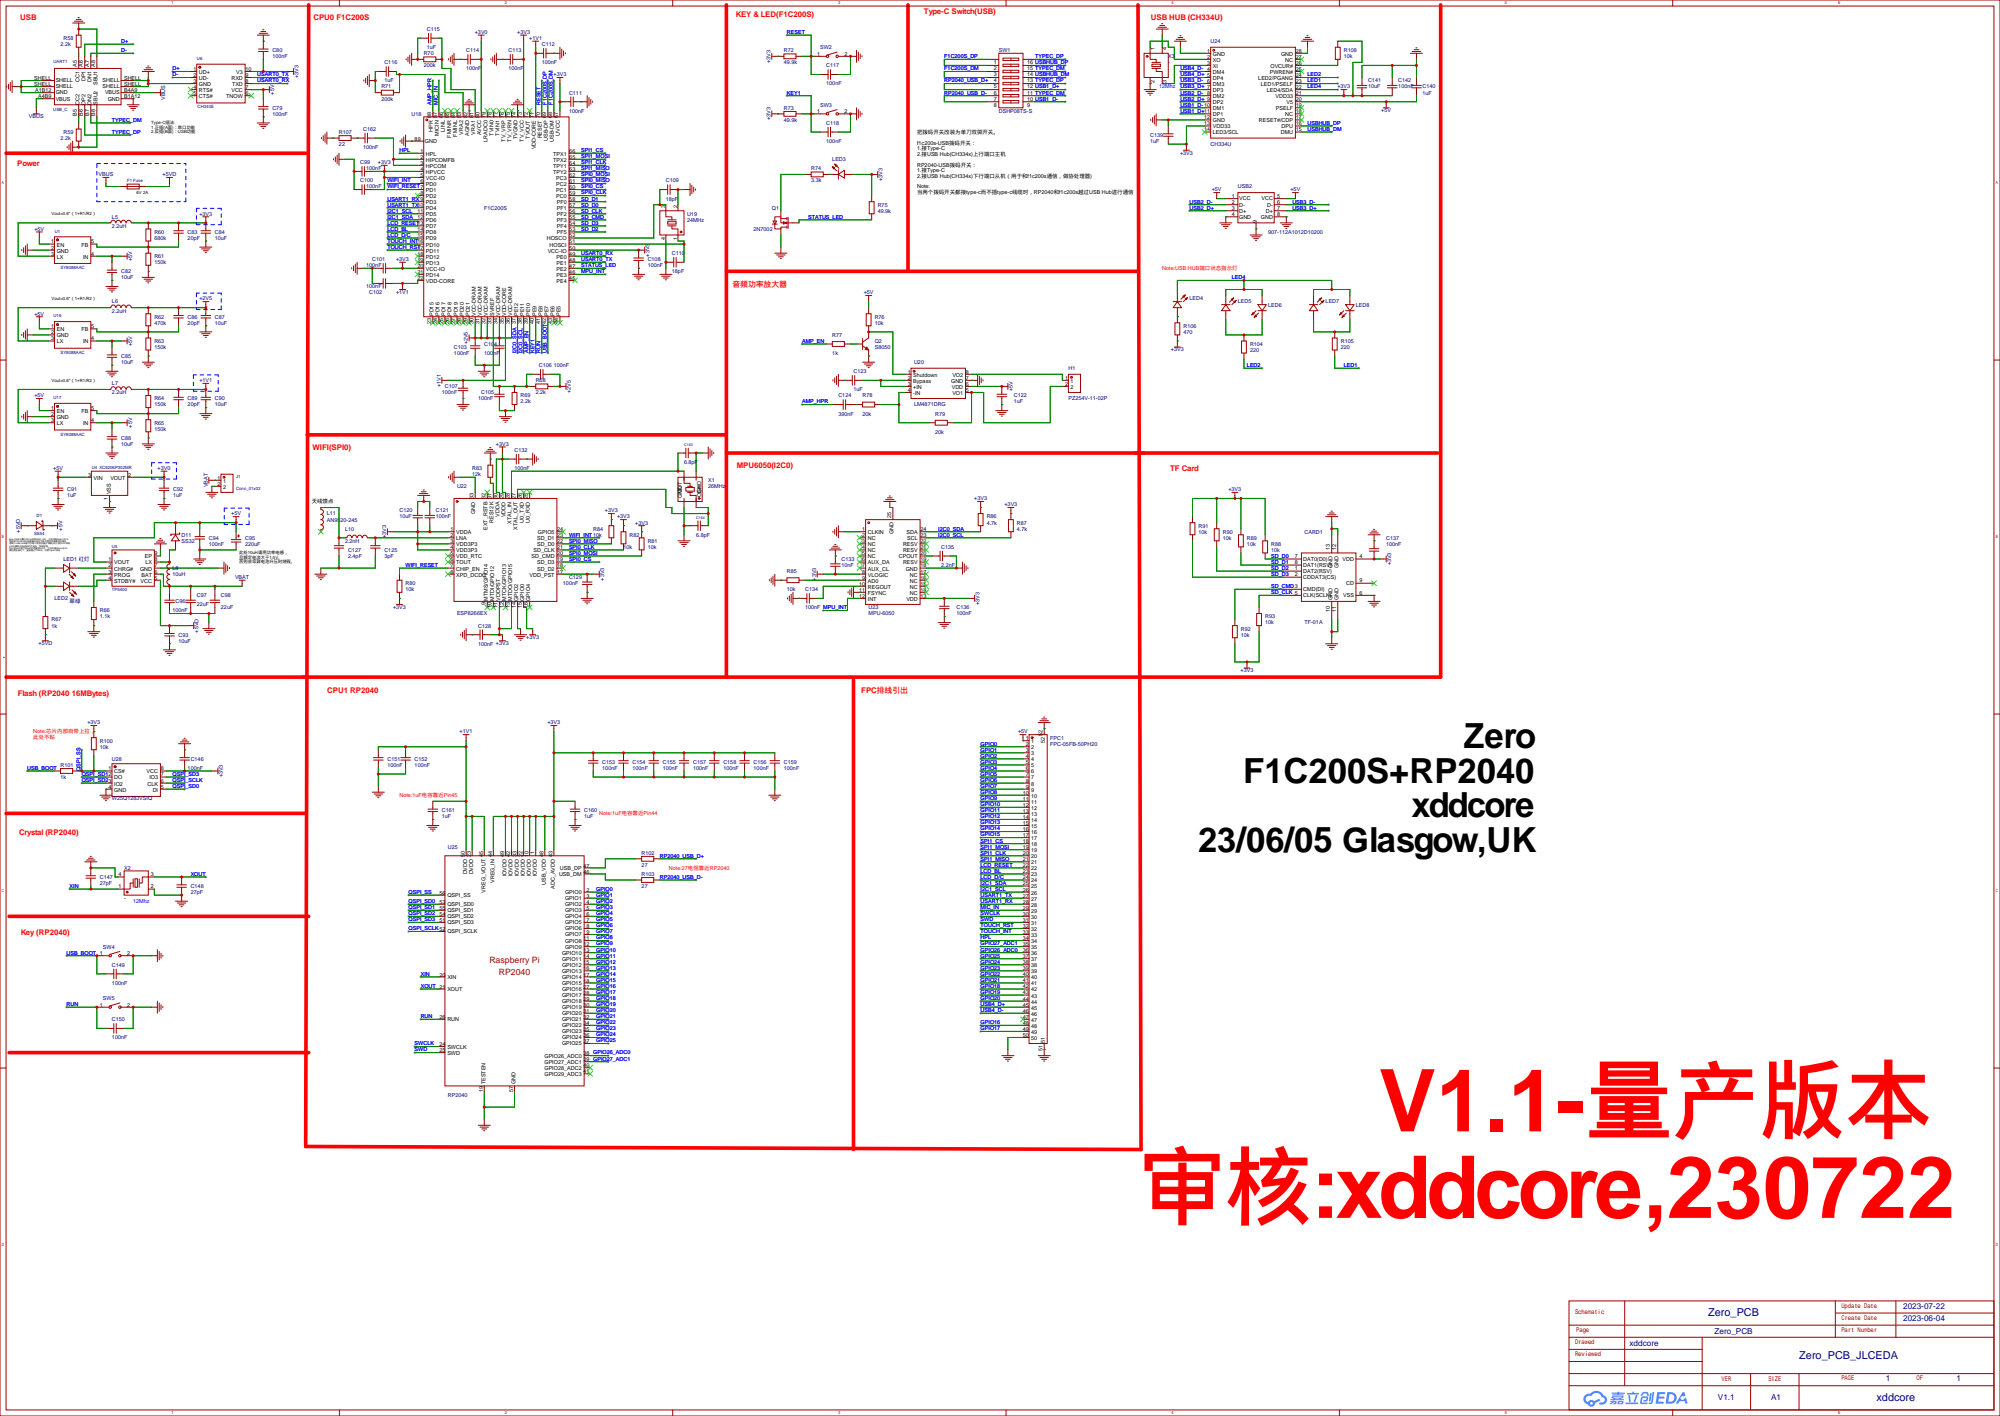
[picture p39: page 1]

RESET
PE4 45 PE3 46 PE2 47 PE1 48 PE0 49 VCC-IO 50 HOSCI 51 HOSCO 52 PF5 53 PF4 54 PF3 55 PF2 56 PF1 57 PF0 58 PC0 59 PC1 60 PC2 61 PC3 62 TPY2 63 TPY1 64 TPX2 65 TPX1 66 UVCC ⁶⁷ USB⁻DM ⁶⁸ USB⁻DP ⁶⁹

Note:1N5819属于SS14(封装SOD-123)，正向压降500mV@1A
考虑到TP5400升压电路输出电流可能不满足设备需求的情况
(例如1.USB HUB接大负载 2.其他设备(扩展板)从引出的FPC取电
3.WIFI瞬间开启造成的大电流，导致压降。
所以将SS14换为SS54(封装兼容2010)，正向压降550mv@5A
满足某些情况下，直接越过TP5400，外接Type-C供电

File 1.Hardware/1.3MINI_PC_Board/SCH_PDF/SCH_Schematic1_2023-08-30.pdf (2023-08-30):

# FPC Input

# 排母引出

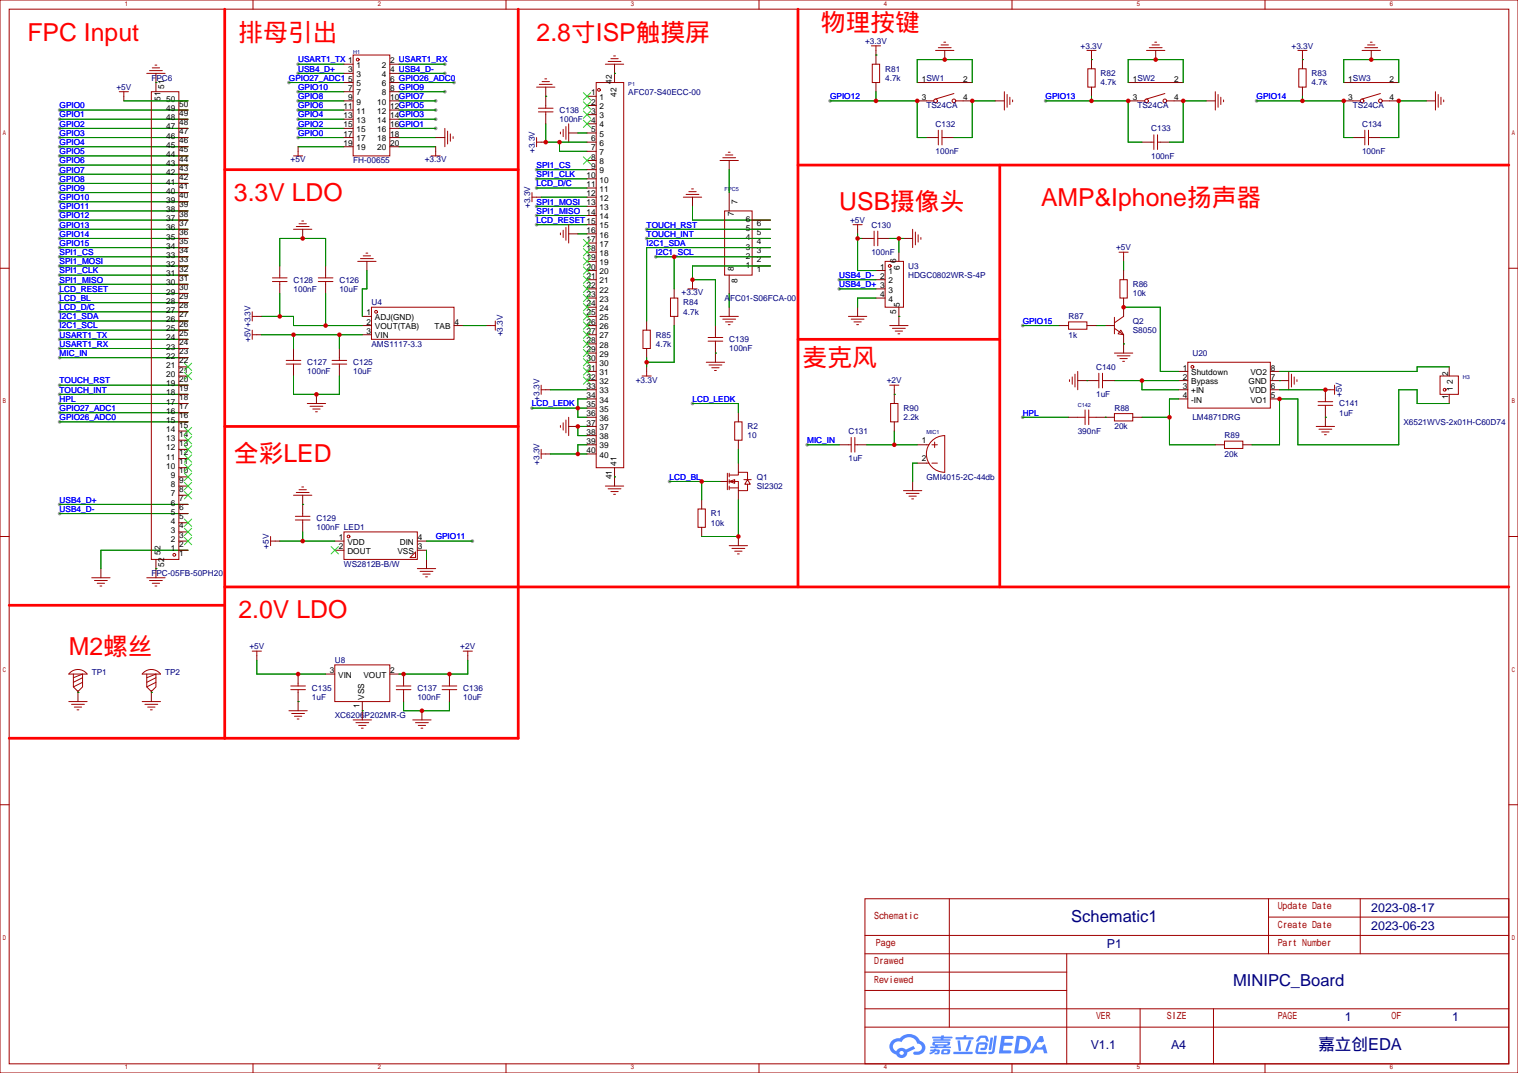
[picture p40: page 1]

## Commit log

2023-06-09 时间线记录
2023-06-11 上传透明探索版外壳渲染图
2023-06-11 提出关于外壳款式的构想
2023-06-11 上传基础款外壳效果图
2023-06-12 2d dwg文件绘制
2023-06-20 更新README
2023-07-19 上传Zero Linux Board V1.1硬件
    [3D_Zero_PCB_2023-06-11 v10(仅有外壳).step]
2023-07-20 更新亚克力组装方法说明
2023-07-20 更新Type-C连接方式教程
2023-07-20 更新量产拼单信息
2023-07-20 上传BOM表
    [BOM_Zero_PCB_Zero_PCB_2023-07-20.xlsx]
2023-07-20 增加若干说明
2023-07-20 上传circuitpython demo
2023-07-21 更新关于WIFI稳定性的测试结果
2023-07-22 Bug:TP5400升压电路功率电感额定电流
2023-07-23 增加锂电池极性说明
2023-07-24 更新小电视扩展版外观&sysbench测试
2023-07-24 更新小电视外壳螺丝要求
2023-07-25 小电视tv项目更名为minipc项目
2023-08-16 更新README，补充相关信息
2023-08-30 上传Zero Linux Board & MINI PC Board & MINIPC外壳生产资料
    [BiliBiliTV v70-外壳1.stl, BiliBiliTV v71-扩展版固定扣1.stl, BiliBiliTV v72-拓展版固定扣2.stl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]
2023-08-31 更新uboot超频配置说明
